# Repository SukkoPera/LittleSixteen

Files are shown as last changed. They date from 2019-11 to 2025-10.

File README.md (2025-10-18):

# LittleSixteen





LittleSixteen is an Open Hardware remake of the Commodore 16, 116 and Plus/4 home computers, featuring many improvements over the original design.

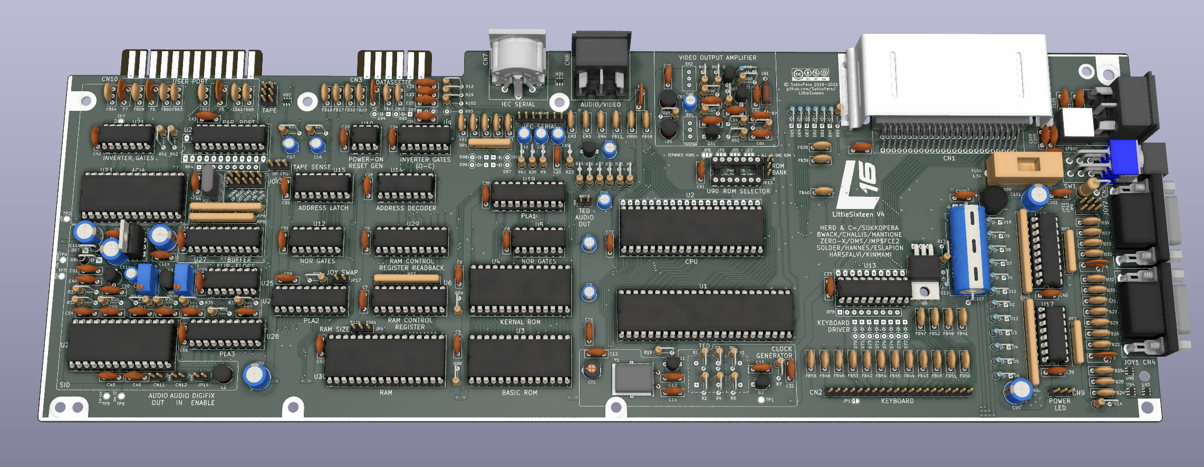
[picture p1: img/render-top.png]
Board


## Summary
While this project started as a simple redrawing of the C16 schematics, it has now evolved into what could be considered the flagship member of the 264 family of Commodore computers, since it has all the characteristics of the other models [^nospeech] and bears a full array of extra features and improvements, while keeping full compatibility with them.

The new goal of this project is to allow anyone to build a very significant home computer from the '80s from scratch, only using parts that can be found on the market [^almost]. The design is fully through-hole so no particular soldering skills are required for the assembly. The estimated cost of ALL materials (case and power supply included) for a single complete machine is around 250-300€.

## Differences and Improvements
The original Commodore 16 was the victim of several cost-cutting measures during its design phase. Its target price was $99 and Commodore still had to have some margin on that, so they really had to spare every cent they could and they went as far as not mounting the decoupling capacitors for a few chips which happened to have another one "close enough". Thus, a further goal of this project was to undo all of those measures and make the design as clean as possible, while also improving on it.

### Modifications introduced in V4
The goal of V4 was to make LittleSixteen an improved Plus/4 clone, rather than a C16 clone.

- 100% Plus/4 compatible User Port.
- 512 kB Hannes-style RAM expansion (which can be reduced to 256 kB through a single jumper for compatibility reasons).
- 2 ROM banks, each of which can carry the whole set of ROMs: KERNAL + BASIC + Function ROMs.
- Onboard SID (either 6581 or 8580 + Optional Digifix) + 3rd joystick port (SID audio is mixed with the TED/Ext audio with configurable volume but direct dedicated output is also available).
- Direct TED audio output connector.
- Joystick swapper.
- Ability to replace keyboard MOS 6529 with 74x273 (so that 6529 can be recycled for User Port, but that one as well can be replaced with a 74x654).
- Removed FB13 in order to reduce luma/chroma crosstalk and improve video quality.
- Pin header with all tape signals (think Internal Tapuino).
- Pin header with all IEC signals (think Internal SD2IEC).

### Modifications introduced in V3
In V3 we started making improvements to the board. The reasoning behind every modification is detailed on the [Development Blog](https://hackaday.io/project/182543-littlesixteen-commodore-16-mainboard), so I'll be pretty terse here.

- Switched to external power regulation, using the C64 power circuit and power supply: drastically reduces the heat inside the case, which is one of the main CPU/TED failure causes.
- Added current-limiting resistors on all ports exposing power pins: this will avoid short-circuiting the power supply, whatever you do on the external connectors.
- Added internal Joystick port buffers: this is basically like having two [OpenC16JoyAdapter](https://github.com/SukkoPera/OpenC16JoyAdapter)s built into the machine, preventing the TED pins to be directly exposed on the joystick ports, which is another common cause of TED failures. It also gives the ports a fixed ground, allowing the use of "advanced" joysticks with autofire functionalities for instance, which require power from the machine.
- Joystick ports now use DB-9 (more properly: DE-9) connectors, just like any other machine of the era: you can now use your favourite C64/Amiga joystick on your C16.
- Similarly, the Datassette port was changed to the C64-style edge connector. An adapter to keep connecting the 1531 Datassette is trivial to make.
- Moved to the C64 power switch, since this can still be found on the market and is functionally equivalent.
- The CPU can now either be an original 7501/8501 or even a 6510, thanks to [Andrew Challis's adapter](http://hackjunk.com/2017/06/23/commodore-16-plus-4-8501-to-6510-cpu-conversion/) being integrated on the board.
- In a similar fashion, the board can either directly accept an original MOS 251641 PLA or [Daniël Mantione's GAL16V8-based reimplementation](https://www.freepascal.org/~daniel/c16pla/).
- The design flaw that prevented the usage of cartridge-based RAM expansions was fixed: you can now plug in an [OpenC16RamExpansion](https://github.com/SukkoPera/OpenC16RamExpansion) without the internal RAM fighting with it.
- Actually that might not even be necessary, as the board now directly supports either 16 or 64 kB of internal RAM.
- Since the RF modulator is basically useless these days, a [replacement circuit](https://github.com/mbarszcz-pcb/c64-rf-modulator-replacement) was integrated on the board, providing either Luma+Chroma (say S-Video) or Composite Video.
- Added the possibility of combining the KERNAL and BASIC in a single all-in-one ROM: this allows replacing the original power-hungry chips with a single W27C512, which can also incorporate the Plus/4 function ROMs.
- ESD protection was improved on all ports.
- The track and ground plane layout were optimized in a few places in order to reduce noise and crosstalk.

While the comprehensive switch of connectors to the C64 counterparts might be frowned upon, it was done because [C64-style cases](https://icomp.de/shop-icomp/en/shop/product/c64c-case.html) are still in production and this way LittleSixteen V3 will fit them just perfectly, yielding the ability to build new C16s from scratch, which is another one of our goals.

### Modifications introduced in V2
V2 was meant to be a 1:1 copy of the original board with some essential improvements requiring minimum effort. The goal was to have a proved-working design we could start from in order to make improvements.

- The original board was probably laid out by hand and a lot of tracks were drawn with arbitrary slopes. I have sticked to only 45 degrees tracks, which of course means I could not follow the original tracks exactly, but I tried to stay as close to them as possible and to keep all the "visual hints" that allow identifying a track quickly. I must admit I'm quite satisfied of the end result, to be honest.
- I used my usual track widths and via sizes (plus some new values for the larger tracks), I didn't bother figuring out what sizes the original board used.
- All tracks were laid out "by eye", which means with *reasonable* - not *maniacal* - accuracy to the original design. Most care was taken in the positioning of components that ought to be in a certain position (i.e.: screw holes and I/O connectors), to ensure drop-in replaceability. Other components and tracks are "more or less" there, but as the board was wholly laid out from scratch by hand, don't expect sub-millimeter accuracy.
- The footprints for all DIP chips use "long pads". This makes them easier to solder and more solid to the board should you need to rework them. This forced a few tracks running very close to the original pads to be slightly offset away.
- Some footprints are slightly longer/larger/wider pitch/whatever than the originals, so that I could use ready-made KiCad libraries.
- Footprints for the connectors and modulator were taken from [StormTrooper's Plus/4 remake](https://github.com/StormTrooper/Commodore-Plus4), without checking them for correctness.
- I didn't bother to create the right footprint for the original power connector, as there's no point in wasting time for some item that is nowhere to be found these days. I used a much more common one instead. Same goes for the inductor.
- I didn't pay much attention to the silkscreen, many labels can probably be placed better, but I added a description for every IC, like it or not.
- Proper footprints were added for all the protection diodes that Commodore forcibly retrofitted on real boards (See D96-99).
- With the C16, Commodore went as far as saving a few cents by not mounting the decoupling capacitors for a few chips. They left the pads on the board but removed all silkscreen indications. These were restored and assigned random numbers.
- The ground fill is autogenerated by KiCad, so it won't match the original exactly (not even close).
- Probably there's something more I've forgotten.

If you don't like any of the above, feel free to fix it yourself and [submit a Pull Request](https://github.com/SukkoPera/LittleSixteen/pulls).

## Testing
V3  and V4 of the board were throughly tested by project collaborator Edoardo Auteri, as you can read on the [Development Blog](https://hackaday.io/project/182543/log/202804-how-to-make-the-changes-that-change-everything). In his words:

> The machine works flawlessly providing superior audio and video performance, low power consumption and compatibility with the 1530 Datassette Unit (C2N model), SD2IEC, Atari joysticks and pads.

## Assembly
If you want to build your own board, **please make sure read the assembly notes on [the Wiki](https://github.com/SukkoPera/LittleSixteen/wiki) carefully!**

Note that there are different pages for different revisions of the board.

## Releases
If you want to get this board produced, you are recommended to get [the latest release](https://github.com/SukkoPera/LittleSixteen/releases) rather than the current git version, as the latter might be under development and is not guaranteed to be working.

Every release is accompanied by its Bill Of Materials (BOM) file and any relevant notes about it, which you are recommended to read carefully.

**I am not providing ready-to-use gerber files**. If all you want is **to get boards made, I would really appreciate if you did so [in a way that supports the project](#support-the-project)**.

## License
The LittleSixteen documentation, including the design itself, is copyright &copy; SukkoPera 2019-2025 and is licensed under the [Creative Commons Attribution-NonCommercial-ShareAlike 4.0 International License](https://creativecommons.org/licenses/by-nc-sa/4.0/).

This documentation is distributed *as is* and WITHOUT ANY EXPRESS OR IMPLIED WARRANTIES whatsoever with respect to its functionality, operability or use, including, without limitation, any implied warranties OF MERCHANTABILITY, SATISFACTORY QUALITY, FITNESS FOR A PARTICULAR PURPOSE or infringement. We expressly disclaim any liability whatsoever for any direct, indirect, consequential, incidental or special damages, including, without limitation, lost revenues, lost profits, losses resulting from business interruption or loss of data, regardless of the form of action or legal theory under which the liability may be asserted, even if advised of the possibility or likelihood of such damages.

## Support the Project
If you want to get some boards manufactured, you can get them from PCBWay through this link:

PCB from PCBWay (https://www.pcbway.com/project/shareproject/LittleSixteen_V4_Build_your_own_Commodore_16_Plus4_fc5ed0cc.html)

You get my gratitude and cheap, professionally-made and good quality PCBs, I get some credit that will help with this and [other projects](https://www.pcbway.com/project/member/shareproject/?bmbid=41100). You won't even have to worry about the various PCB options, it's all pre-configured for you!

Also, if you still have to register, [you can use this link](https://www.pcbway.com/setinvite.aspx?inviteid=41100) to get some bonus initial credit (and yield me some more).

You can also buy me a coffee if you want:

<a href='https://ko-fi.com/L3L0U18L' target='_blank'>Buy Me a Coffee at ko-fi.com</a>

## Thanks
- My father, for buying me my C16 when I was 8, my first computer ever. This project is dedicated to his memory.
- Amiwell, for giving me a free C16 that I used to trace a lot of connections.
- [StormTrooper](https://github.com/StormTrooper/Commodore-Plus4) for his similar project about the Plus/4, which is where many of the footprints and 3D models used in this project come from.
- J. F. Gomez, for the [3D model of the Barrel jack](https://grabcad.com/library/dc-power-jack-5-5mm-x-2-1mm-2-54mm-pitch-1).
- [Edoardo Auteri](https://github.com/kinmami), for his invaluable advice on analog stuff and for fully assembling the first prototype and testing it thoroughly.
- Gordon Fecyk AKA Great White Retro, for beta-testing, making videos of his builds and spreading the word.
- Last but not least, thanks to [PCBWay](https://www.pcbway.com) for sponsoring the project and providing us with free prototypes of V3.

[^nospeech]: Ok, ok... No V364 speech support, I'll admit!
[^almost]: Almost, the CPU, TED and Expansion port connector must be recovered somehow.

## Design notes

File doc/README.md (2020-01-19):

8501 die shots:
http://visual6502.org/images/pages/MOS_8501_die_shots.html

7501/8501 pin info:
https://ist.uwaterloo.ca/~schepers/MJK/7501.html

Tech docs:
https://www.pagetable.com/?p=541

6529_replacement_for_C16.gif by Dr Jefyll:
http://forum.6502.org/viewtopic.php?t=3067#p34914

Useful info:
https://www.associazione64.it/home/il-commodore-16/#ics

Modulator Rauswerfen:
https://www.forum64.de/index.php?thread/44092-hf-modulator-rauswerfen-c64c/

http://cbm-hackers.2304266.n4.nabble.com/CPU-Replacement-for-die-264-series-td4501523.html
About GATE IN:
 From the TED system manual:

R/_W is latched by the Gate In line to synchronize between a DRAM memory
cycle and the processor clock cycle. If AEC is low when Gate In makes a
low to high transition, the R/_W line will go to a high impedance state
until the next transition of Gate In and AEC is high prior to the
transition.

It shouldn't be difficult to make that work, but so far I haven't been
able to come up with a small and simple circuit for it. It would be nice
if 2 TTL chips were enough.

---

Yes the gated R/w line was the major difference, it was to keep the /WE
enable line valid compared to the DRAM cycle instead of the Phi clock
cycle.  I don't remember if any other changes were installed in the
processor later other than I think I remember that the port became a 7
bit.  I seem to remember that if the unused bit isn't always returned as
the same bit then the code could hang, so tie the unused port to 1 or
something if emulating with 8 bit.

I think I did the Gated Read/Write with a 74LS73 only I drove the GR/w
line high, not HiZ.

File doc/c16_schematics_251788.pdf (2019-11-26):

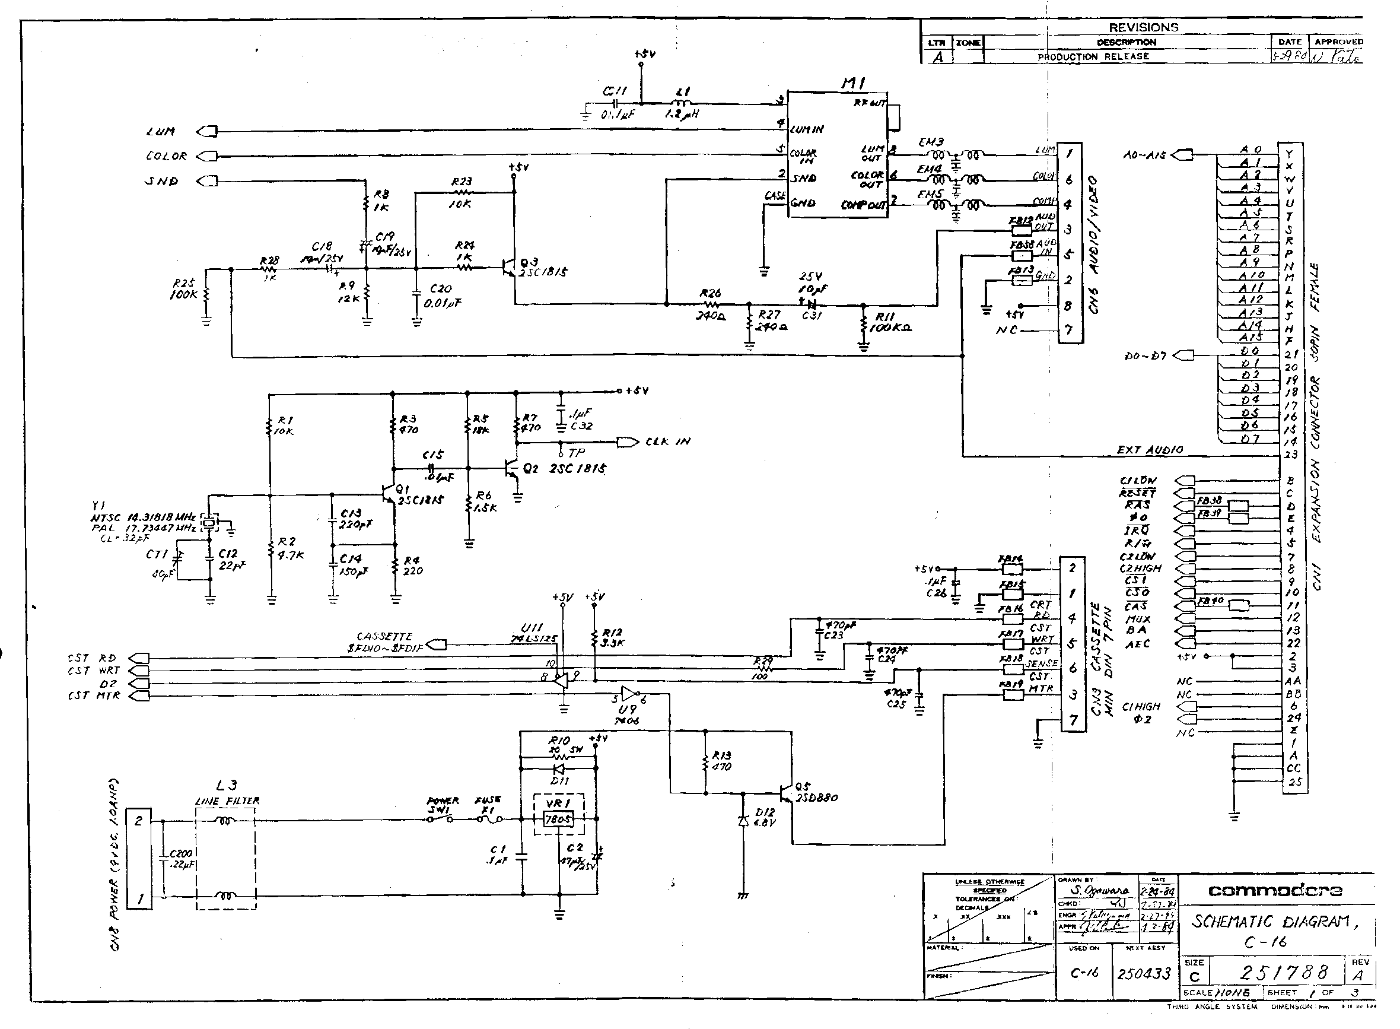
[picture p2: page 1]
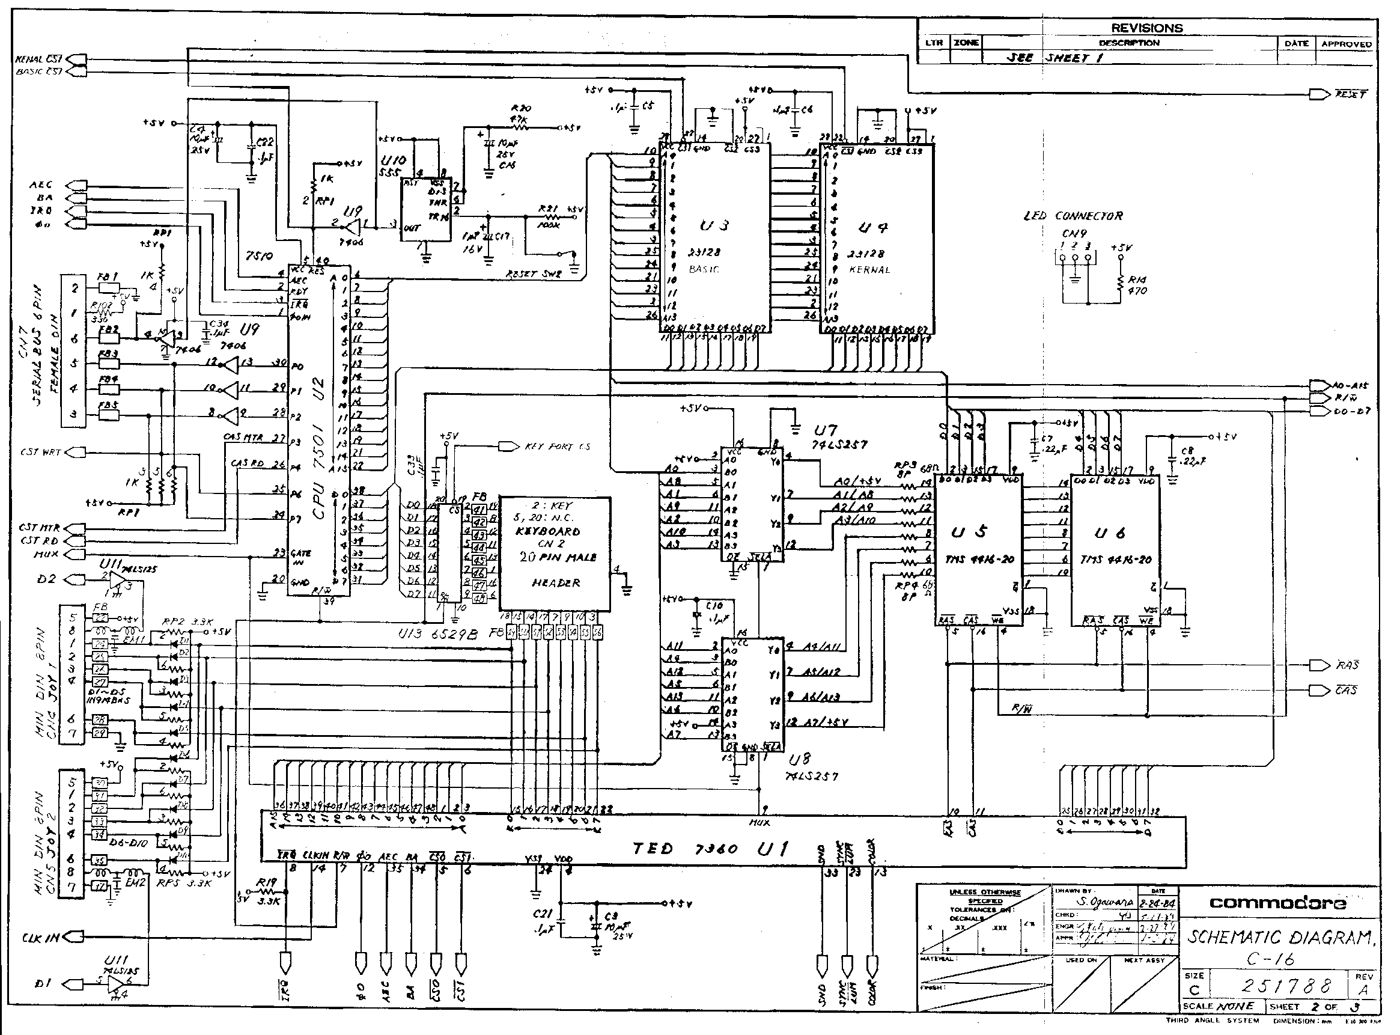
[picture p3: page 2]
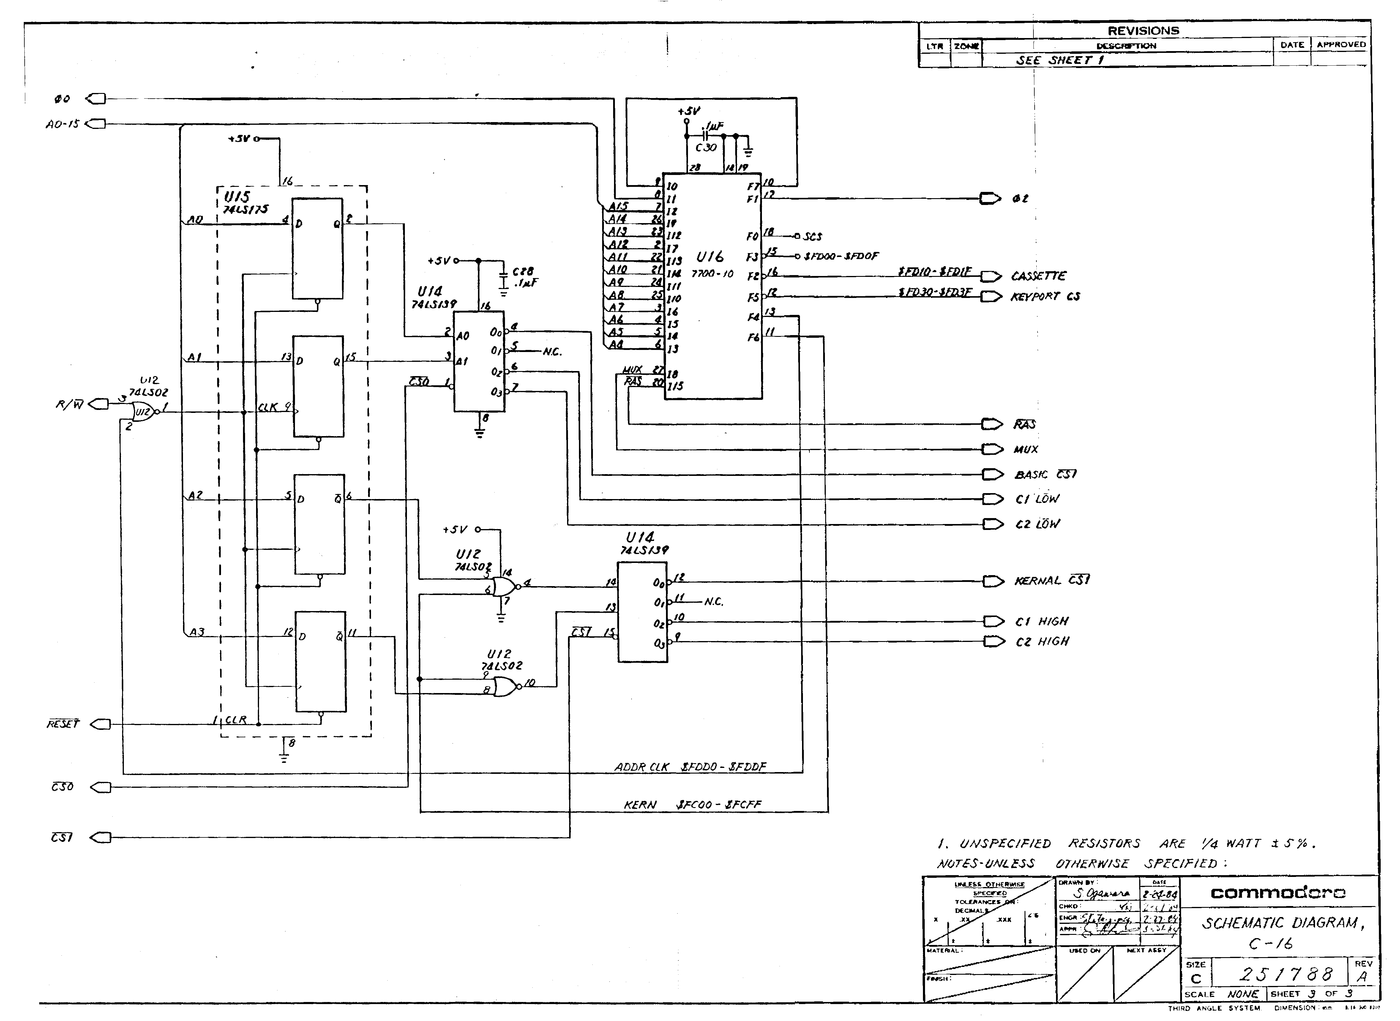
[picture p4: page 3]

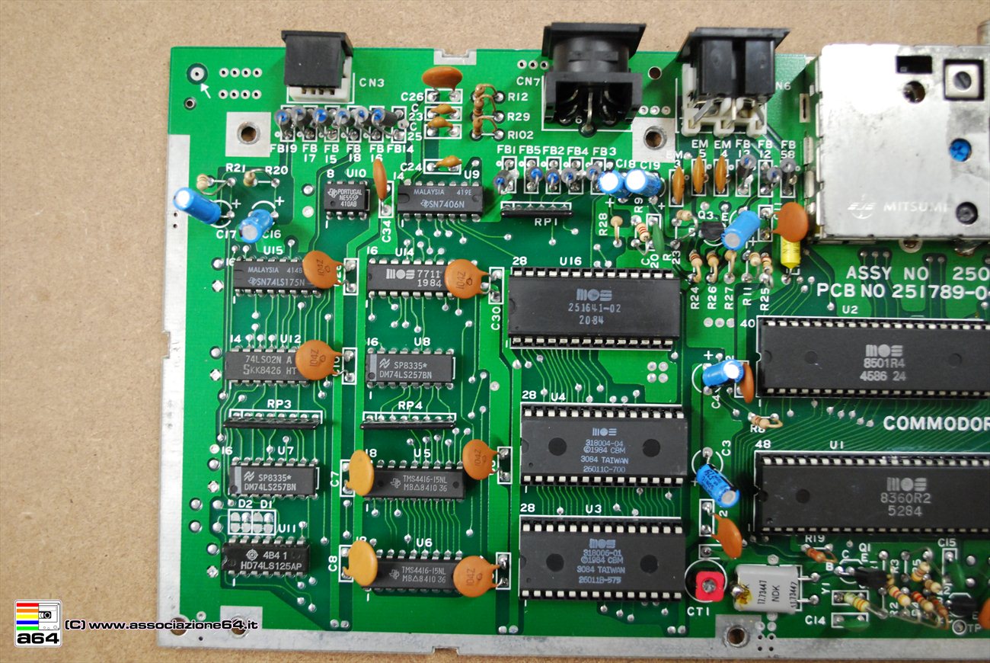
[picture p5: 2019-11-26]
doc/Commodore16_002.jpg

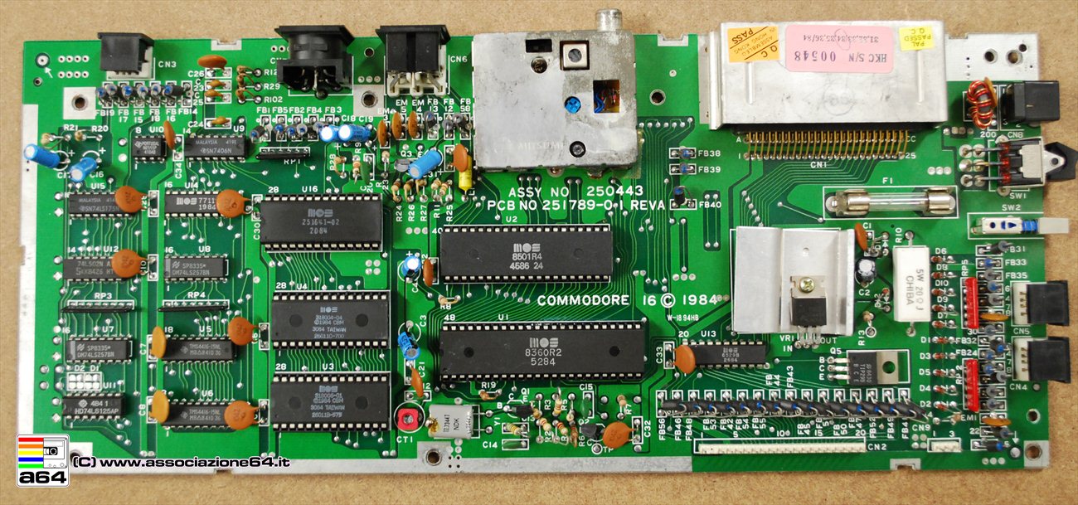
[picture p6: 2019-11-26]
doc/Commodore16_001.jpg

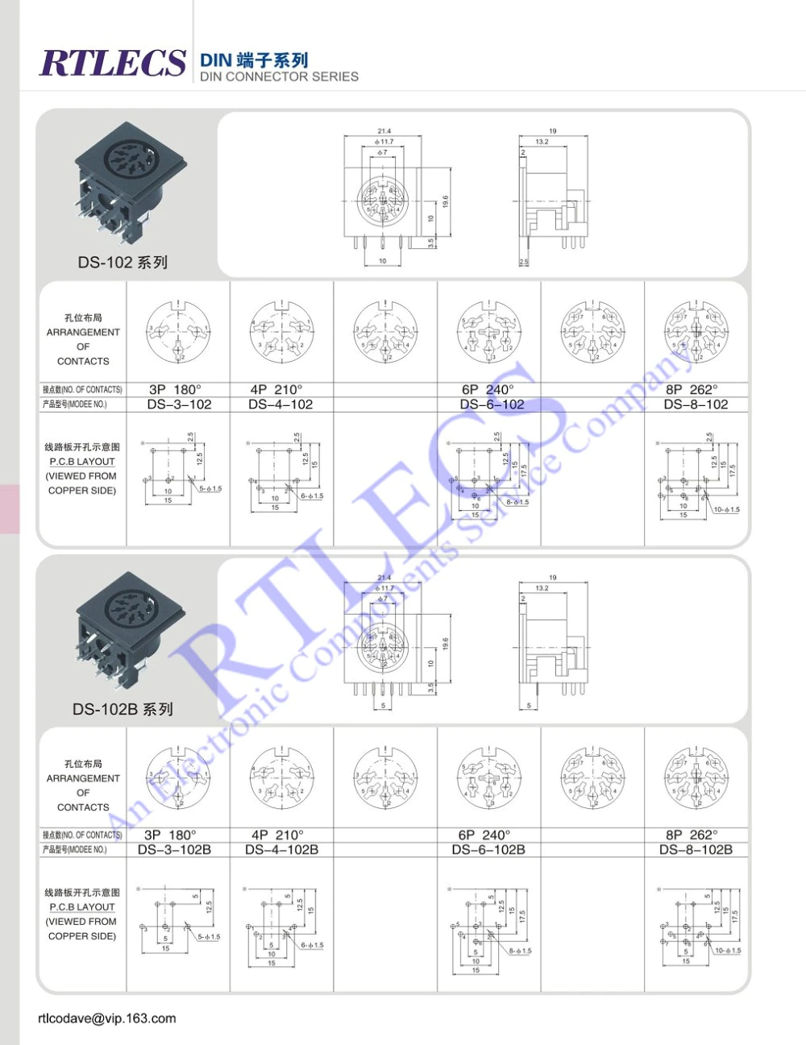
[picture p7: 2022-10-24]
doc/din_connectors.webp

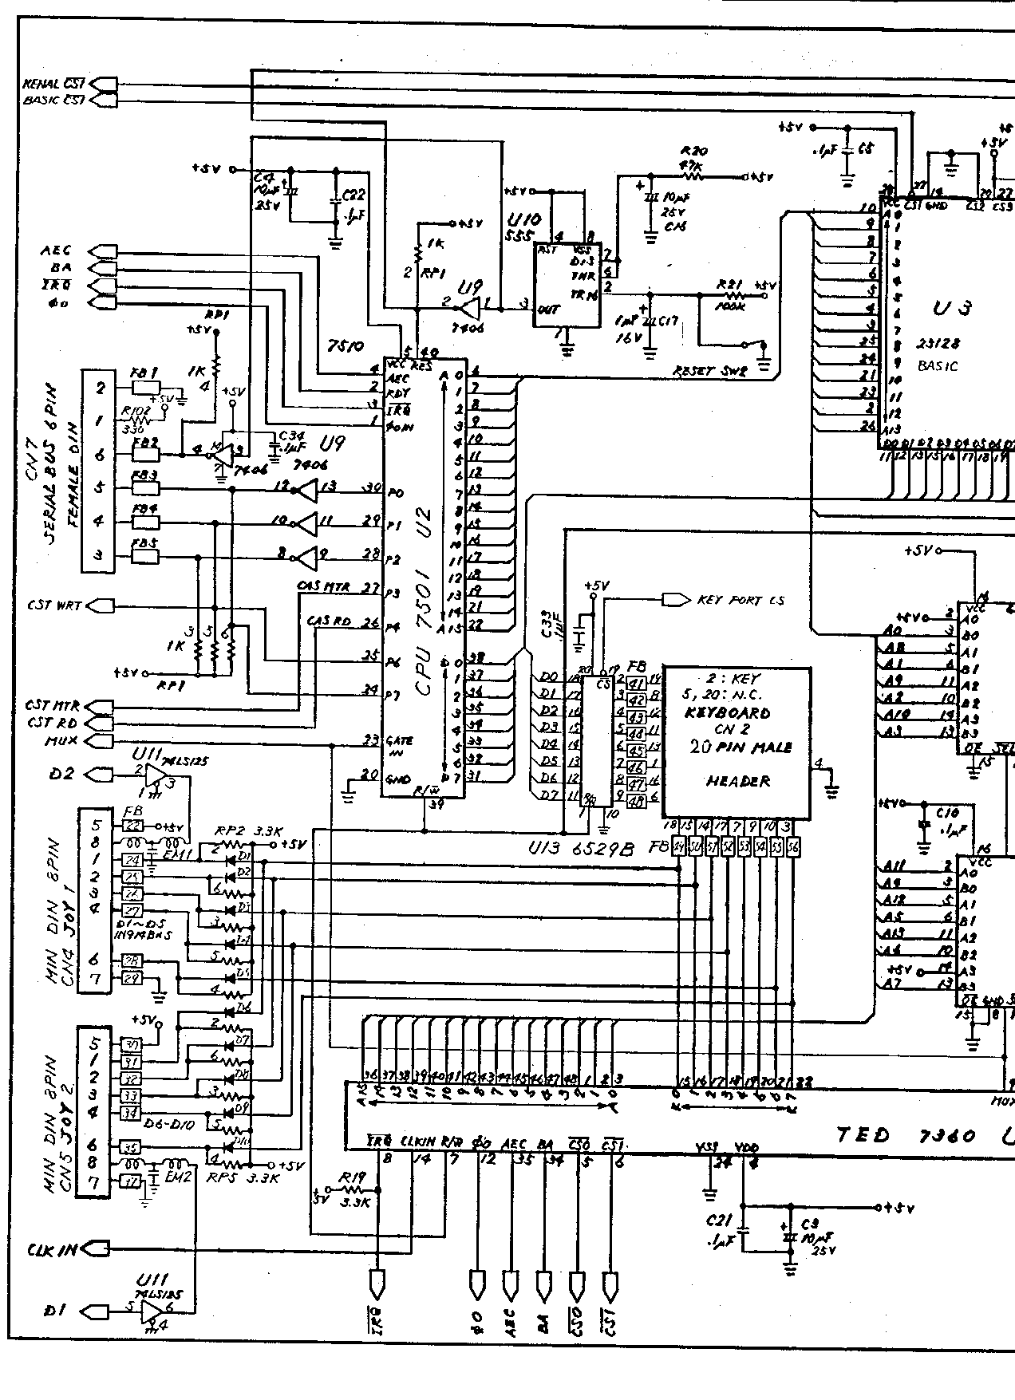
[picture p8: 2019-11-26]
doc/c16-251788-2of3-left.gif

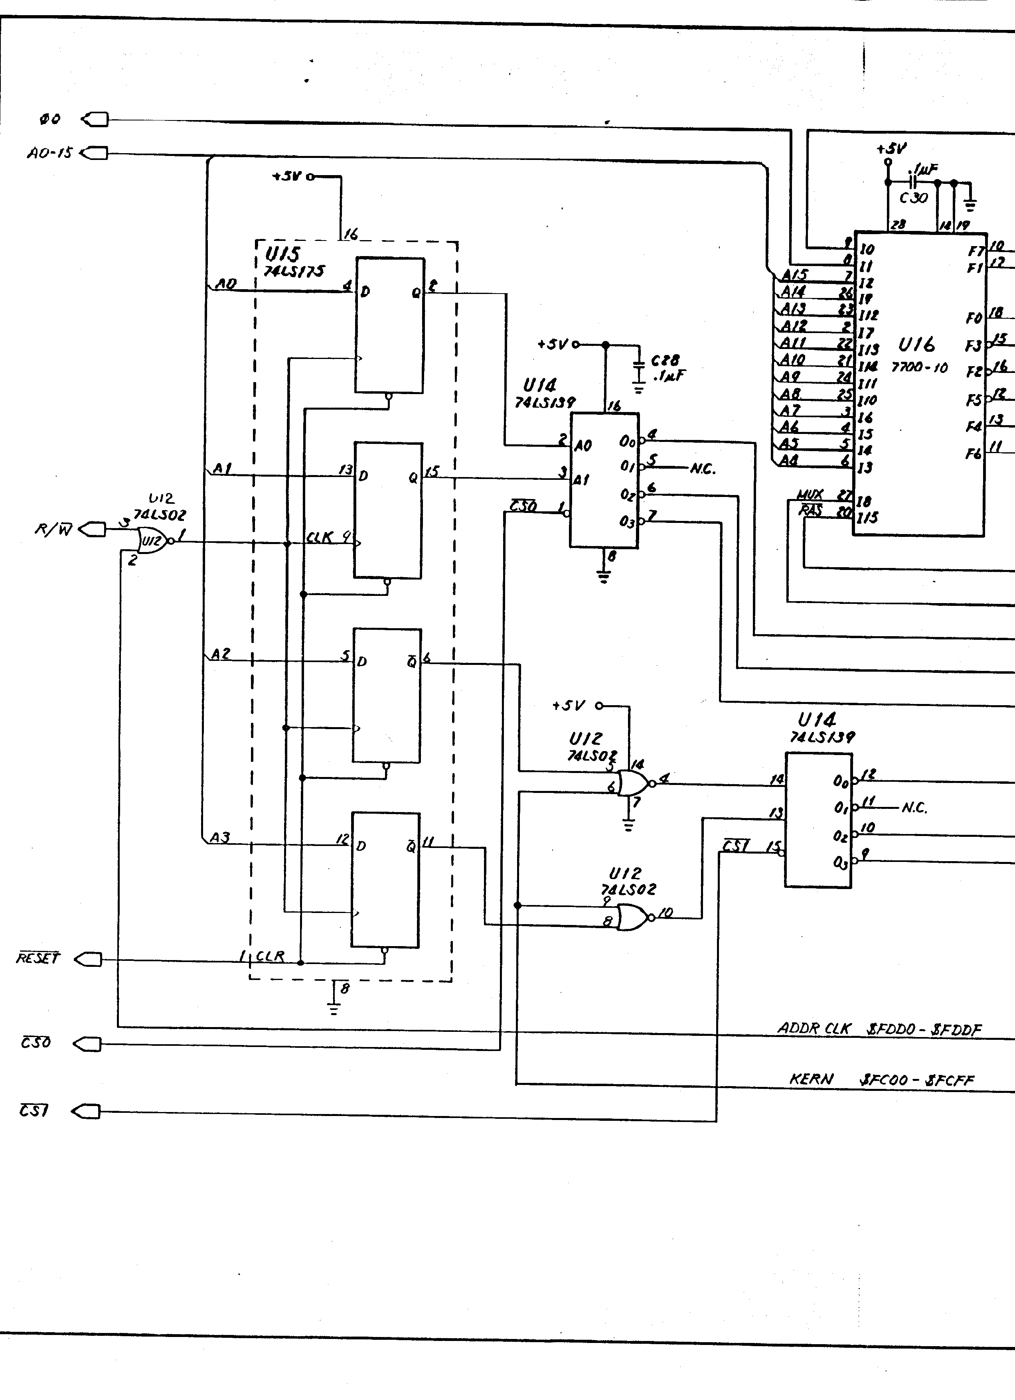
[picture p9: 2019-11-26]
doc/c16-251788-3of3-left.gif

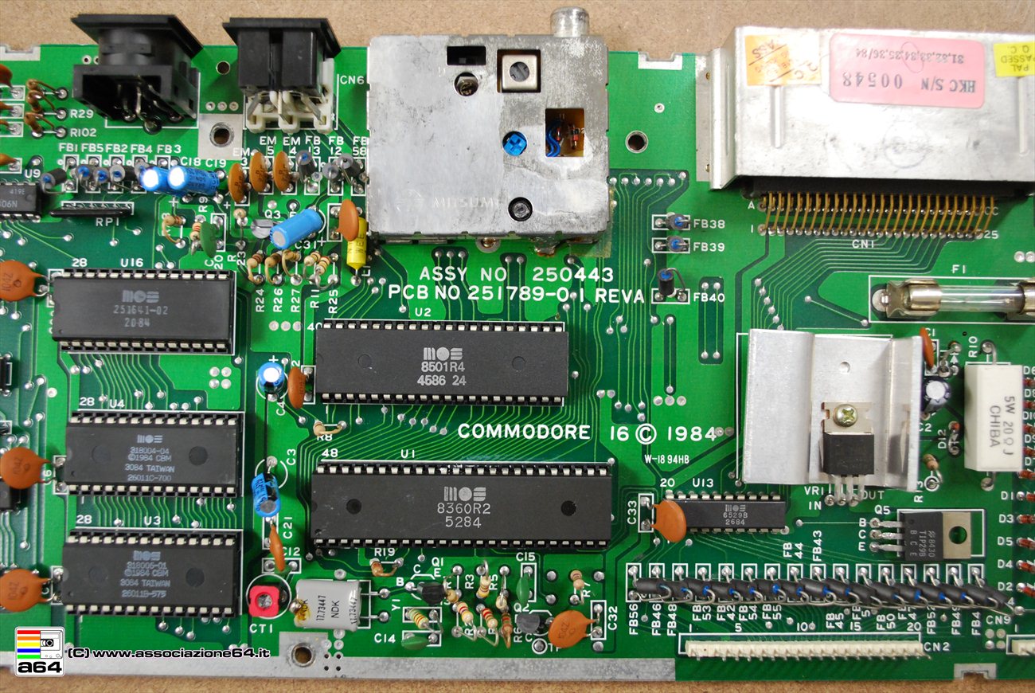
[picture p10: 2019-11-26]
doc/Commodore16_003.jpg

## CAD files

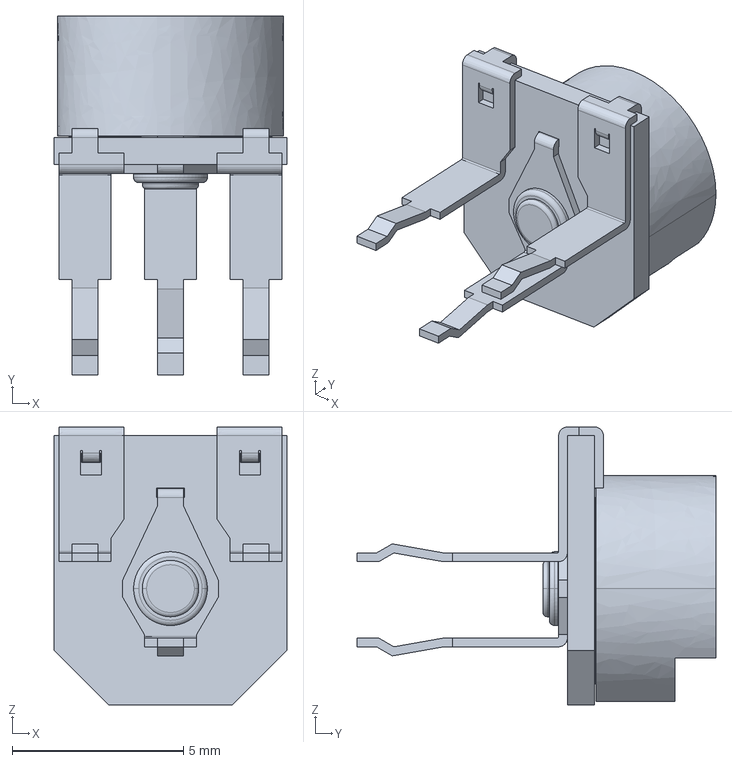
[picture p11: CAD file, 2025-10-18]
3dmodels/3306p-1-101.stp
6.81 x 10.5 x 8.13 mm

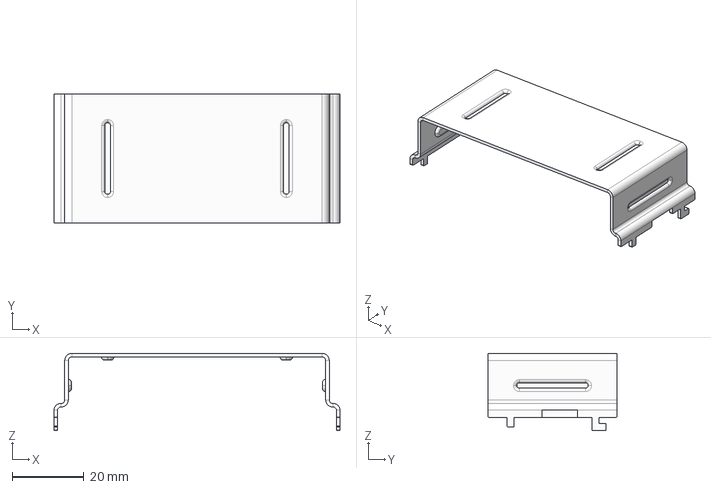
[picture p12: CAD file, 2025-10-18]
3dmodels/Expansion_Port_Cover.step
80.0 x 36.0 x 21.6 mm

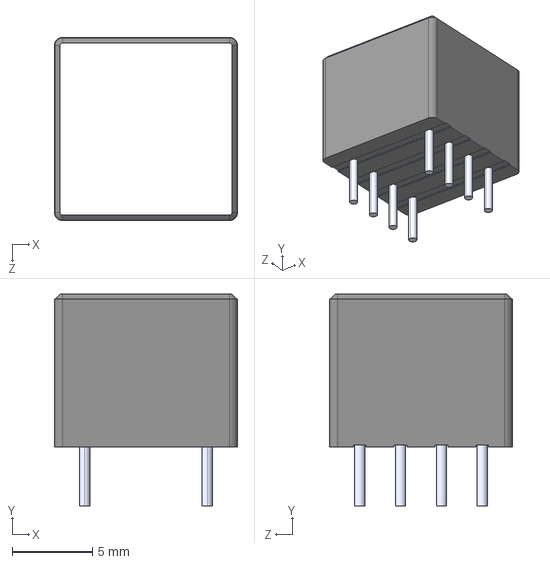
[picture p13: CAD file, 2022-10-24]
3dmodels/CM4545Z131B-10.step
11.4 x 13.2 x 11.4 mm

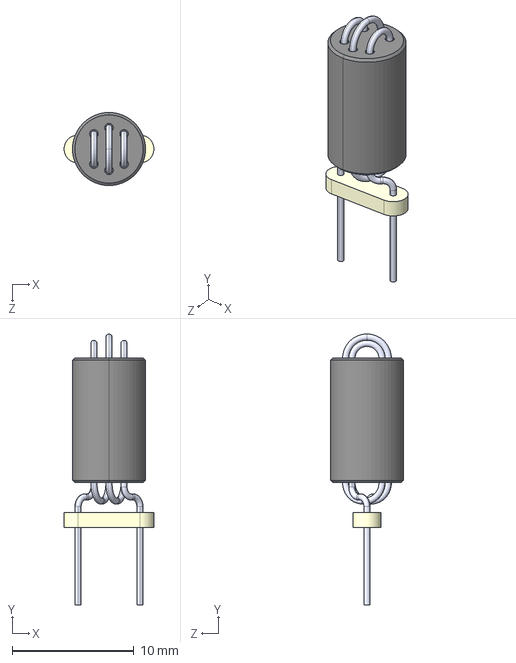
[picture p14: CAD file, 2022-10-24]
3dmodels/28C0236-0JW-10.step
7.37 x 22.2 x 6.00 mm

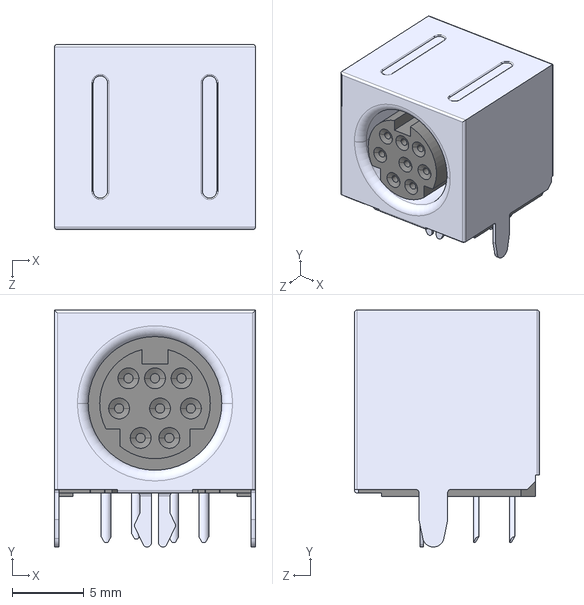
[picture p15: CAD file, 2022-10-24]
3dmodels/KMDGX-8S-BS_rC6.step
14.0 x 16.5 x 12.9 mm

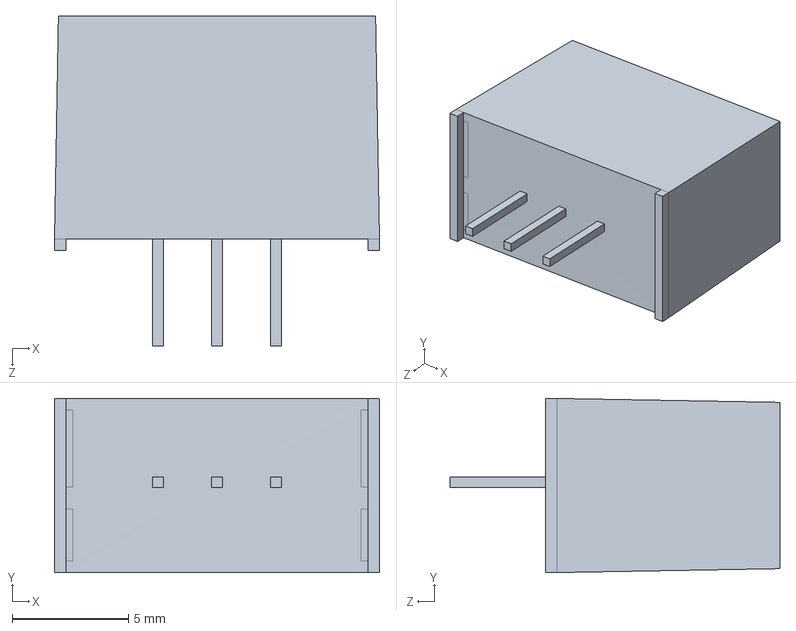
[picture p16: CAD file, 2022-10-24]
3dmodels/tsr2_3d_drawing.stp
14.0 x 7.50 x 14.2 mm

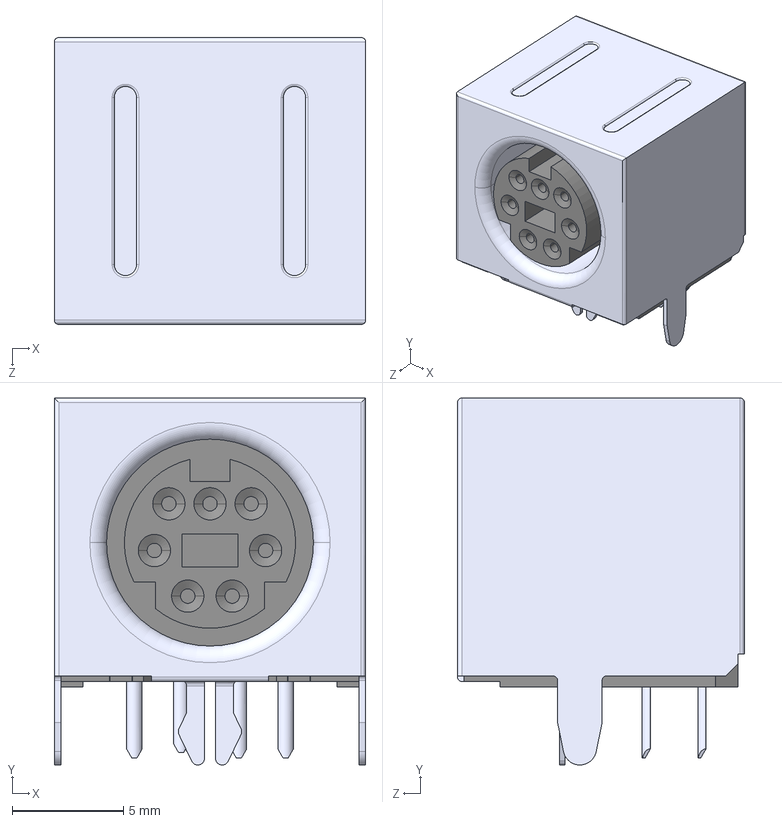
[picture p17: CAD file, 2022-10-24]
3dmodels/KMDGX-7S-BS_rC6.step
14.0 x 16.5 x 12.9 mm

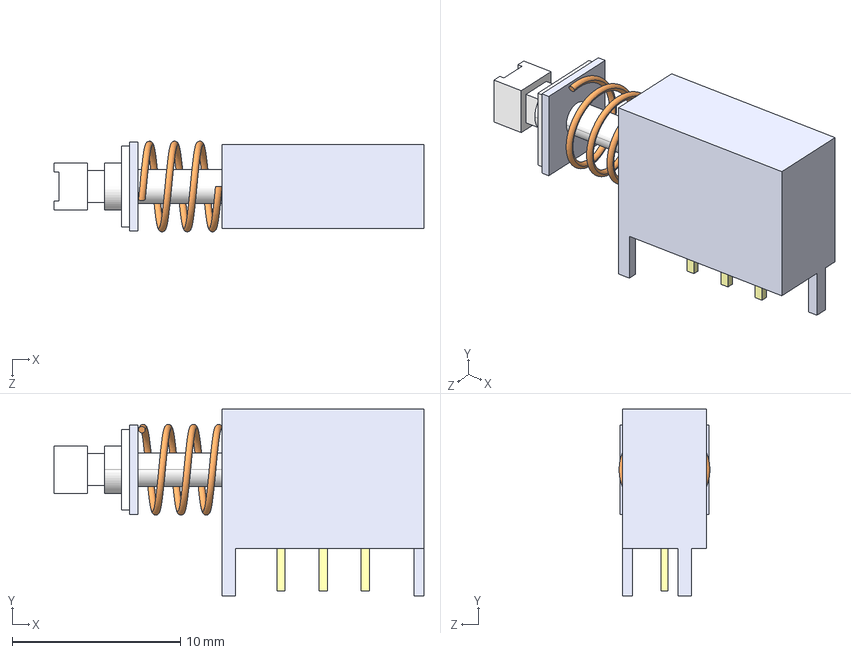
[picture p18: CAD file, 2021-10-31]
3dmodels/pushbutton-switch.step
22.0 x 11.1 x 5.40 mm

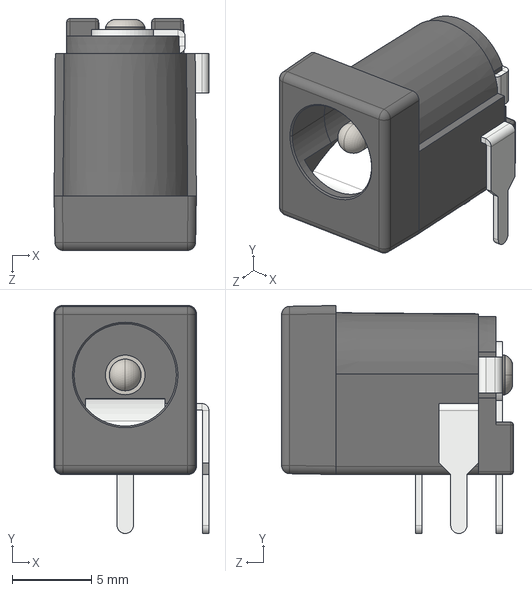
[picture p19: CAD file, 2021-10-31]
3dmodels/DC Power Jack 5.5mm x 2.1mm.STEP
9.77 x 14.4 x 14.6 mm

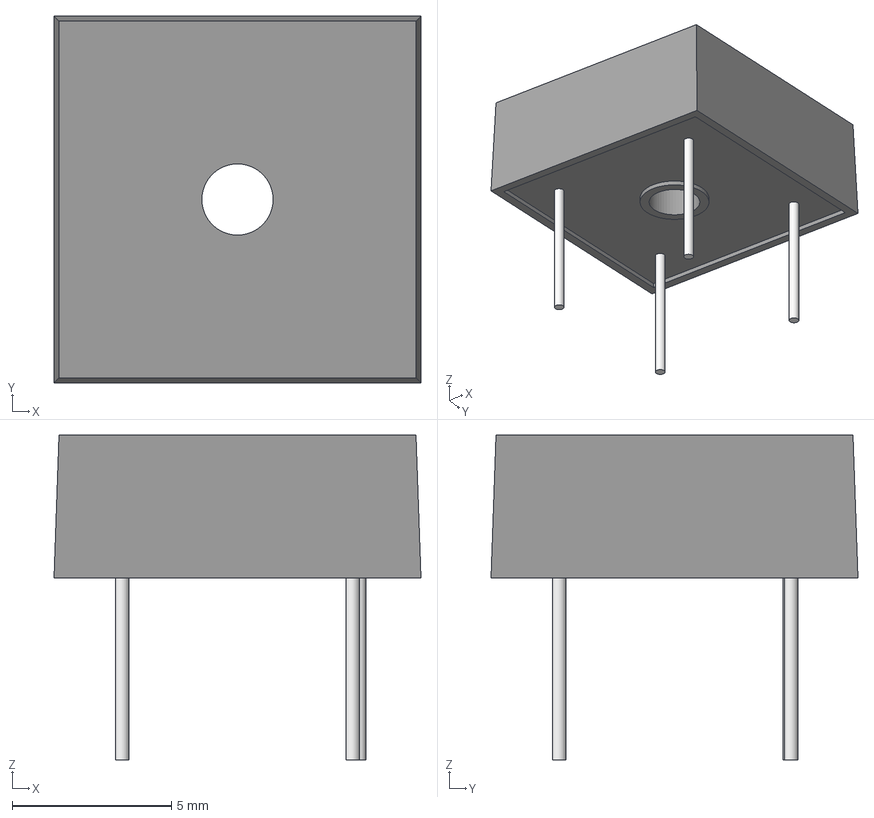
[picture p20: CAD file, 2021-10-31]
3dmodels/rectifier.step
11.5 x 11.5 x 10.2 mm

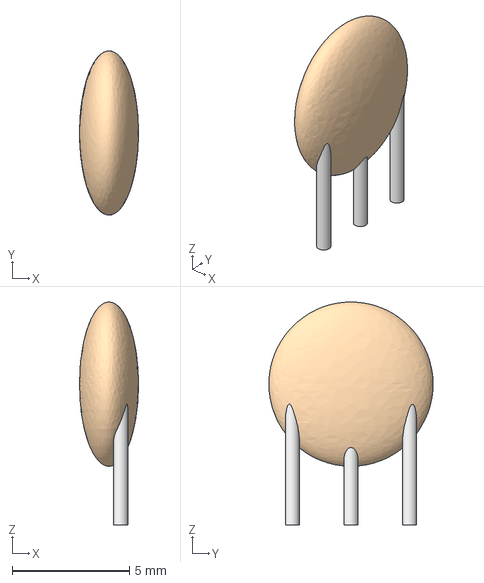
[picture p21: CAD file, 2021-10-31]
3dmodels/DSN6.step
2.52 x 6.99 x 9.50 mm

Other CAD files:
3dmodels/DSN6.FCStd

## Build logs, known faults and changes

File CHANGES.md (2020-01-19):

## CHANGES

Any modifications to the LittleSixteen design and documentation made by any Licensee MUST be noted in this file, as per *section 3.4.b* of the [license](LICENSE.pdf).

### (Date) - (Author)
(Description)

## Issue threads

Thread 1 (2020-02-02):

Looking over your schematics

bwack, 2020-02-02:
Hi SukkoPera ! I'm looking over your schematics, mainly just because of curiosity and interest :)

I found a mistake at page 11: C11 is connected on wrong side of L1.

I will notify you if I find more.

Hans/Bwack

bwack, 2020-02-02:
Page 10 (PLA): Addr_clk and KERN mixed up on U16 PLA.

bwack, 2020-02-02:
- Page 9 (power):
  - Looks like wrong power switch, and resting at ON position.
  - comment to R10 big white resistor. It provides about 200mA extra current. (9-5)V/20 ~ 200mA. It is very odd!
  - U11E and U9G on wrong page.
- Page 8: Exp conn:
  - BRESET ?
- Page 7 (cassette and disc drive):
  - The RP1 and CST WRT is shared with the disk drive signal on p6. Not clear in the schematics that p6 is shared, though I do see it now maybe because I have the original next to the new one.
  - p0..p7 on page 2 and 7: I would call them by signal name rather than cpu port io name in my opinion. I got confused.
- Page 6: I'll skip this page. It should be redrawn.
- Page 5 (ROM): OK
- Page 4 (RAM): OK
- Page 3 (TED and clock): OK
- Page 2 (CPU): OK

other:
Check pinout of all bipolars.
page 6 (keyb): I don't like this page. I like the original better. At least the P0..P7 part. I do like the comments though.
page 5 (ram): double check RP3 and RP4 connections. Original schematic is not clear here.
Page 10 (PLA): F0 and F3 looks like test/connection points in original schematics but not in new schematics. What is most correct?

Thats it. Overall, very nicely done!

SukkoPera, 2020-02-02:
Hi @bwack, it's a honor to have someone like you check my work :).

I will go through all your observations as soon as I am finished with the project I'm currently working on.

Thanks a lot, I really appreciate it!

SukkoPera, 2020-10-04:
I finally had a look on these, the fixes are in the fix_errors branch. In detail:

> page 11: C11 is connected on wrong side of L1.

Fixed.

> Page 10 (PLA): Addr_clk and KERN mixed up on U16 PLA.

Fixed.

> Page 9 (power):
>   Looks like wrong power switch, and resting at ON position.

This can be addressed in the PCB footprint (if ever).

>   U11E and U9G on wrong page.

Well, U9 and U11 are used in more than one page, so I felt the best place to put their decoupling caps was the Power page.

> Page 8: Exp conn:    BRESET ?

Since it is unnamed on the C16 schematics, I probably took this name from the +4 schematics, where it is defined as *Buffered System Reset*.

> Page 7 (cassette and disc drive):
>    The RP1 and CST WRT is shared with the disk drive signal on p6. Not clear in the schematics that p6 is shared, though I do see it now maybe because I have the original next to the new one.
>    p0..p7 on page 2 and 7: I would call them by signal name rather than cpu port io name in my opinion. I got confused.

As far as my KiCad knowledge goes, this is the best I can do. That's why I also added text labels clarifying the signal names.

> Page 6: I'll skip this page. It should be redrawn.
> I don't like this page. I like the original better. At least the P0..P7 part. I do like the comments though.

You are probably right, but I really don't feel like doing this at the moment. I'm all open for contributions though ;).

> page 5 (ram): double check RP3 and RP4 connections. Original schematic is not clear here.

This was traced by myself on a real board. I know it looks very odd but it simplifies the routing, that's why they did it like that, I guess.

> Page 10 (PLA): F0 and F3 looks like test/connection points in original schematics but not in new schematics. What is most correct?

I have no idea what *SCS* means for F0, while F3 is uses on the +4 as the ACIA CS. I have added in a note for the latter.

I think we can close this and open a new ticket for page 6, asking for help. Any comments?

SukkoPera, 2020-10-25:
I'm closing this as I fixed all I could. Feel free to open a new issue if you have any more comments :).

bwack, 2020-10-25:
Hi. Glad I could help :) I haven't had time to look at this again. I looked at page 6, and yes it is a lot of work to change it. What I didn't favor was the crossing. What commodore did there was to change the number order on the keyboard pin symbol.
And easy fix could be to remove all the wiring from the key connector and U13, use buses. I can try that if you like.

SukkoPera, 2020-10-25:
Sure, go ahead if you feel like it :).

bwack, 2020-12-22:
Hi Long time. I just remembered something about the work that I did on the schematics. Please use a larger grid, or try not to change the grid in schematics. A very simple job turned into a much harder one. Just saying.

SukkoPera, 2020-12-23:
I don't think I ever changed the grid size. Not willingly, at least.

I will (hopefully) have a look at your contribution during the holidays, sorry for the delay.

bwack, 2021-05-01:
Sorry about the misguided blame. I spoke with a guy on facebook. He said that in KiCad 4 there was a bug where the symbols had an 0.1mm offset to the grid, and it was fixed at a later point (causing more trouble hehe). At the time when I imported this project into kicad 5, it led me to believe you had used a tiny grid.

Closed 2020-10-25.

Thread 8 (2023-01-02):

using the 6502 instead

giobbino, 2023-01-02:
Hello!
Amazing project!
I was wondering about the chance to use a 6502 as CPU using this project:
https://github.com/monotech/MOS_CPU_Replacer

of course one could build the adapter, but maybe it would be fine to add it directly on the board (of course if there's enough space left on the board to do that...)

Well, just a thought...

SukkoPera, 2023-01-02:
That would be a very good idea, but:
1. It hadn't been released yet when I did this (or at least I was not yet aware of it);
2. It seems to still have a few compatibility issues;
3. It requires way more components than can fit on the current board.

I will definitely take it into consideration if the remaining issues are fixed AND if I ever switch this to SMD components, which would probably allow us to reclaim quite some space.

Thanks for your thoughts anyway 😉.

giobbino, 2023-01-02:
I understand. Also, I bought some boards from JLCPCB with the idea to have them ready on hand, just in case; however, since luckily everything still work fine here at home, I didn't test it yet - so I don't know if those adapters work fine or not.
cheers!
P.S. sukkopera = succo di frutta alla pera? I love it too ;-)

SukkoPera, 2023-01-03:
Well, the author of that adapter seems to know what he's doing :). I still haven't tried it either but I am keeping an eye on it.

PS: That's it, but I actually hate succo di frutta alla pera :).

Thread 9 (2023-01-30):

C64 keyboard

wiikroskop, 2023-01-30:
I built LittleSixteen but I had only the C64 keyboard.
The keyboards are very similar, but the C64 keyboard doesn't work with the C16.
 I found this article
[https://www.amigalove.com/viewtopic.php?t=1181](url)
and I resoldered the wires on the PCB keyboard to C16 standard colors.
It works fine, but it has some limitations.
Restore key doesnt work, Right Shift is ESCape , + is cursor down (!) , - is cursor up, pound is cursor left , clr is cursor right,
@ is - , up arrow is +, left arrow is Home , cursor left/right is pound, cursor up/down is @.

I found another article
[https://www.pagetable.com/?p=1050](url)
and based on that I remapped the keys in the ROM layout to the C64 layout with the exception
right shift and left arrow.

This solution does not work when the program reads the keys directly, but eg. FB16 ( filebrowser 16 ) works fine with my SD2IEC

use at your own risk :-)

SukkoPera, 2023-01-30:
Thanks a lot for the information :).

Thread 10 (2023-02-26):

Wrong Value for C15

SukkoPera, 2023-02-26:
Someone reported that C15 should be 10 nF rather than 10 pF. Original schematics seem to say ".01 uF", so report is probably correct.

SukkoPera, 2025-01-04:
Fixed in 17af5a4 for V4

Closed 2025-01-04.

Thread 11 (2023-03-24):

BOM for Little Sixteen V3 Board

Snocksman, 2023-03-24:
Hi !

Is there a BOM for the little Sixteen V3 Board available ? I ordered some Boards but could not find a BOM yet.

Greetings
Mathias

SukkoPera, 2023-03-24:
Nope, haven't had time to put one together yet. Maybe you can help with it? You can start with what you can find in Kicad.

Snocksman, 2023-03-24:
OK, i´ll have a look at Kicad. So I have something to do at the weekend... ;D
When I got the BOM ready, you can add it to this cool project.

SukkoPera, 2023-03-24:
Yup, let's leave this open then!

Snocksman, 2023-03-26:
Hi !

I have found most of the Components, but for some i need a few more informations/values (maybe an example part):

CT1
D12
EM3, EM4, EM5
FB2, FB3, FB4,...
FB12, FB13, FB14,...
L1
L81

Thank you !
Best,
Mathias

SukkoPera, 2023-03-28:
In our test build we used DSS1NB32A101Q91A for all EM* and FB*, totalling 51 of them. These filters are better than ferrites, but they also used to be more expensive, so Commodore only used them where essential, falling back to ferrites wherever possible.

These days I can't seem to find any reasonable ferrite that is significantly cheaper, so using filters everywhere is probably the best option. This one MIGHT do, but you're not going to save much anyway:

https://www.mouser.it/ProductDetail/Fastron/BEAD-4-900R-02

@kinmami: Any thoughts about that?

RP1, RP2 and RP5 are BUSSED.
RP3 and RP4, RP90 and RP91 are ISOLATED.

Other P/Ns from our test build:
CT1: EW Electronics GKG50015
D12: NZX6V8D,133 (Make sure to see the Errata page on the Wiki)
L1: Bourns 9250A-122-RC
L81: TE Connectivity SC30100KT

kinmami, 2023-03-28:
https://www.digikey.com/en/products/detail/laird-signal-integrity-products/28L0138-80R-10/1015875

https://www.mouser.it/ProductDetail/Laird-Performance-Materials/28L0138-80R-10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

SukkoPera, 2023-03-28:
I'll leave the word to @kinmami :).

kinmami, 2023-03-28:
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

Yes I think all of those above are compatible, thanks

msuontausta, 2023-03-30:
Here's our list: https://docs.google.com/spreadsheets/d/1dDgSGAWIuUnK9-j-XhQTBRzt-erFqXx8YhXyfMe616A/edit?usp=sharing

It's a bit rough around the edges and comments are in Finnish but all of the necessary information should be there. :)

SukkoPera, 2023-03-30:
Yeah! Thanks a lot! 👍

Snocksman, 2023-04-01:
@msuontausta Hey, thats cool. I could put my Reichelt order Information next to it, but I have only read permissions on the sheet.

Another question (maybe not really right to that issue): I got a W27C512. Is there any Information in which order i have to put the Basic,Kernal,Char-ROMs to the EEPROM ?

SukkoPera, 2023-04-01:
Yes, if you plan to use the all-in-one ROM, have a look at [this](https://github.com/SukkoPera/LittleSixteen/wiki/V3-Assembly-Notes#roms).

Actually make sure to read the whole document, and take care of the erratas.

SukkoPera, 2023-12-05:
You need to salvage it from an old board unfortunately :(. In V5 we'll turn it to the same connector as the C64, at least that one is still around.

kinmami, 2023-12-31:
Hello.
I have personally tested the listed parts without any problems, so I'm not certain about the root cause.
However, there is a different part number available with a capacitance of 270pF instead of 10000pF. You can try using this alternative part and let us know if it resolves the issue. Here is the link to the product: Murata Electronics DSS1NB32A271Q91A [](https://www.mouser.co.uk/ProductDetail/Murata-Electronics/DSS1NB32A271Q91A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)

kinmami, 2023-12-31:
I have tested PAL machines with different custom chips.
Please try with this ferrite https://www.digikey.com/en/products/detail/kemet/B-01-RS/10442402
It is designed for signal / audio line filtering.

kinmami, 2024-01-17:
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

A word of appreciation for your troubleshooting and reporting. We are going to update the BOM list accordingly.

SukkoPera, 2025-01-02:
Information integrated in the [V3 Assembly Notes](https://github.com/SukkoPera/LittleSixteen/wiki/V3-Assembly-Notes).

(At last!)

Jartza, 2025-01-27:
Hi!

I finally got time to assemble my LittleSixteen and indeed there was an issue with BOM me and @msuontausta  provided. Accidentally the EMI-filter was 10000pF instead of 100pF... these will definitely NOT work, if you have gotten the 10000pF (10nF) filters, do not assemble them but use ferrites instead!

I have updated the BOM sheet and removed link to wrong EMI filter, instead linking to 270pF version (as 100pF doesn't seem to be available in Digikey), and added link to ferrite beads.

Sorry about the confusion.

Closed 2025-01-02.

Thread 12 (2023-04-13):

Board is ready, but all I get is a black screen...

Snocksman, 2023-04-13:
Hi !

I got my Little Sixteen Board ready today and powered it up for the first time but all I got is a black screen. So I read the Wiki again and found out that I had to remove D93 and R93 if I want to use an original 8501 CPU... So I cut off both and tried again but still black screen... So I tested the CPU (maybe I killed it, because of the installed D93 and R93...), but it still works fine in my Plus4.

Is there something that I should do with the jumper pads JP1 & JP2 if I install 64KB of Memory ??? I found nothing about them in the wiki...

Snocksman, 2023-04-13:
OK, I got the Board running. But I have a Problem with the Colors and Picture Stability on my Upscaler.

Here is the picture how it looks like on my original C16:
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

and here how it looks like on my Little Sixteen:
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

About picture stability: The picture stays stable on the upscaler for about a minute, after that it begins wobling in one direction... looks like the characters in the picture start "walking" to the left or to the right...

Without the upscaler (connected to an old CRT), the problem with picture stability is gone, but the color problem is still there.

Any Idea about that ?

SukkoPera, 2023-04-14:
If there's anyone that can help you, that's @kinmami :).

Snocksman, 2023-04-14:
For further Information (Oszilloscope Pictures and so in) you can see my thread  on forum64: [Link](https://www.forum64.de/index.php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)

kinmami, 2023-04-14:
I assume the video cable is 75 ohms and the termination at the CRT monitor (or video upscaler+LCD) is also 75 ohms.
Pls verify on your side if the cable has a series resistor anywhere from 300 to 2K ohm on CHROMA (some cables originally made for the C64 have a series resistor).
Said that, from your scope screen captures I can see the LUMA signal is too intense and it is saturating.
Would you please adjust the trimmer or changing the resistor at the video circuit section to achieve something close to 1Vpp (LUMA) and 1Vpp (CHROMA)?
Hope it helps.

SukkoPera, 2023-04-15:
If calibration of the pots is an issue, note that the wiki has instructions on how to to use fixed resistors in their place, still providing the best output quality, thanks to relentless testing by @kinmami :).

Snocksman, 2023-04-15:
In the cable I use there is a 325 Ohm Resistor in the Chroma connection.
I was able to get a good picture using the trimmers, but the picture is getting "unstable" after a minute, when i´m using the Upscaler. When I turn the trimmer RV2 counterclockwise as far as possible (I get a very dark picture) the picture gets suddenly stable again.

SukkoPera, 2025-01-04:
Video circuit updated in V4

Closed 2025-01-04.

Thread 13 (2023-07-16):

Working with single 27C246

anarkiwi, 2023-07-16:
Hello,

Thank you so much for this wonderful project. I have just built a V3 board and got everything working - great!

I was able to make my V3 board work with just a single 27C256 (because I had trouble sourcing 27C512s) - perhaps a minor modification could be made to make this easier?

After some experimentation I found that I could simply burn kernal + basic to a 27C256, configure the V3 board for "single ROM", and install a single 27C256 instead with the Vpp pin lifted/grounded. It looks then like the C16 kernal comes up, does not find the function ROMs and just drops into regular C16 mode. I have no plans ever to use the function ROMs so this is fine for me.

Maybe an additional jumper could be added to allow the ROMs A15/Vpp to be grounded?

Thanks again for your fantastic work,

SukkoPera, 2023-07-16:
Good suggestion, even if AliExpress is literally full of W27C512 ;). I will have a look and probably do something in this regard anyway. I just don't understand why you suggest grounding the VPP pin, I think it should be tied to VCC for read-only operation. I'll check and let you know ASAP.

Thanks for taking your time to suggest an idea!

SukkoPera, 2023-07-16:
I've checked and I am now sure that VPP must be tied to VCC for normal read-only operation.

This is luckily very easy to do: just put pin 1 back into the socket and solder JP6 in the _Separate ROMs_ position (i.e.: left and center pads). Leave JP5 and JP7 in the _All-In-One_ position. This should work, let me know!

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

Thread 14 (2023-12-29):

New V3 board getting a black screen on power on

MC6809E089, 2023-12-29:
Hi,

Sorry to raise this as an issue but I've just finished building a couple of V3 pcbs (one for me, one for my brother who can't solder so well), but neither board is working at the moment. I was wondering if there are any additonal instructions, or changes that need to be made to get a V3 board working, other than those written on the wiki?

On power up, both boards exhibit the same behaviour: They output a black screen with sync to my retrotink mini, there is no other picture or sound. The boards supply voltages seem fine, 5.1V on the 5V rail, and 6.5V-ish for the tape motor, so I think they're okay. I believe I can see a clock signal, and some sort of activity on the data and address busses (I only have a bitscope, not a proper oscilliscope), and some of the chips on the board get warm after a while, but only warm, not too hot to touch or anything. I've tried the kernal version of 264 diagnostics ROM, and left it running to see if there was any audio, but nothing on screen or via the audio. I wondered if I might have gotten something wrong relating to the ROM/RAM jumpers.

The boards are configured for use with an original 8501 (lower socket), separate ROMs (all jumpers soldered to the left)  and 64k of RAM (both jumpers on the left). Do I need to do anything with JP1 or JP2?

All new components were sourced from Mouser in the US, and from the BOM linked in the BOM issue here. All original components were sourced from a pair working C16s, so that I had something to compare against. Because I built two pcbs, I've been able to swap all of the ICs between the two new boards and the original ones, and all ICs work fine in the original boards, so I believe the issue is somewhere on the new boards, either my bad soldering, or an incorrect component somewhere, rather than a failed one.

I understand that the problem is almost certainly something I've done, and could be pretty much anything but I thought I'd ask in case. Thanks in advance for any help or suggestions you can provide. :)

SukkoPera, 2023-12-29:
First things that come to mind:
1. Make sure that all resistor networks are properly _bussed_ or _isolated_ as they should be.
2. Unsolder FB38/39/40. It's still unclear why but some people experience problems when using RC filters at these positions. If that works, you can replace them with ferrite beads.

SukkoPera, 2023-12-30:
Glad you fixed it.

I don't think a 547 makes any difference wrt a 550. You have to work on the pots or even better remove the pots and just use the standard values as detailed here: https://github.com/SukkoPera/LittleSixteen/wiki/V3-Assembly-Notes#rf-modulator.

Closed 2023-12-30.

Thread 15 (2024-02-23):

V4

kinmami, 2024-02-23:
U91~95 lengthen the pad footprint and add a DOT on pin 1

kinmami, 2024-02-23:
CT1 enlarge the pad holes

kinmami, 2024-02-24:
CN6 pinout is wrong

kinmami, 2024-02-25:
to replace power resistors R91, R92, R94, R95 and R39, R40 with polyfuses (BOM list updated with the commercial p/n)

kinmami, 2024-02-25:
R32 for MOS 6581: to align the schematic and the interactive BOM list

gordonfpanam, 2024-09-10:
> R32 for MOS 6581: to align the schematic and the interactive BOM list

MOS 6581 as in a SID chip? Is this an attempt to integrate the SID for Psytronix TED titles that support SID expansion carts?

SukkoPera, 2024-09-10:
Yes, V4 has a built-in SIDcard. See https://plus4world.powweb.com/forum/47104.

gordonfpanam, 2025-01-05:
I'll be looking for the PCBWay link to order v4 boards as soon as you have it up.

SukkoPera, 2025-01-05:
@gordonfpanam: That's coming in a few days, but if you want I can send you the gerbers and you can order the board on JLC, which should be cheaper.

Closed 2025-01-04.

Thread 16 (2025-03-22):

74LS654 for v4 parallel user port?

gordonfpanam, 2025-03-22:
Going through the BOM for v4 RC16 I double checked looking for U122, a 74LS654. This part doesn't seem to exist in the XLSX BOM, nor is it in stock at DigiKey. Searches are turning up LS645 and similar parts, which have different pinouts compared to the KiCad schematic. The silk screen also specifies a LS654 part.

There is a 74**A**LS654 part that uses open collector outputs, which I suspect is the reason for RP4 being used as pullup resistors. Is this the intended part?

I won't need these parts until later in my build as I'm focusing on the Commodore 16 part first, but I wanted to confirm if I'm supposed to find a real LS part, or if the ALS part will work. I don't have the original MOS 6529s to spare.

SukkoPera, 2025-03-22:
A 74x654 is needed, definitely not a 645 nor anything else.

All 74x654 are open-collector by definition and so is MOS 6529 (but the latter also has internal pullups), that's why this particular part was chosen.

We have tested LS, ALS and ACT parts and they all work, like probably many others.

Unfortunately all of these in the DIP package are not easy to find these days. They have quickly gone out of stock on all the main distributors.

I suggest that you look on eBay or maybe buy [the 6529 replacement by Daniel Mantione](https://www.sellmyretro.com/offer/details/mos-6529-spi-full-equivalent--_-soldering-kit-43923) and just use the 654 chip or even ask him if he can provide a few chips.

gordonfpanam, 2025-03-22:
Is the ALS654 part compatible, then? These at least seem to be in stock at a few places.

Closed 2025-03-22.

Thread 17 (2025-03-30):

No NTSC Colour on v4

gordonfpanam, 2025-03-30:
I'm not getting any colour on NTSC with a 14.31818 crystal and NTSC kernal. Depending on the monitor, I could get either no colour at all in NTSC or PAL, colour in PAL but no colour in NTSC, or colour in PAL but flickering between colour and monochrome in NTSC.

I've already worked back through the video amp circuits, effectively converting both circuits into v3 form, but keeping R86 as 1k to avoid drawing too much current from the TED Sync/Luma pin. I want to work forward toward v4 again until I lose PAL colour, but I've run out of time for now.

I've gathered scope captures of the luma and chroma signals and I'll try to put together a side-by-side comparison video. I've done this for the L16 v4 and for an original Commodore 16 to compare. The original C16 has very hot chroma signals but these work on any monitor in either PAL or NTSC. By comparison, when I do get colour PAL video using the Rev 3 circuits I can dial things back to 1V peak to peak (1VPP) on luma and 0.3VPP on chroma, which is supposed to be s-video spec according to The Retro Channel:

https://www.youtube.com/watch?v=agDFLPP9yIw

Doing the 1VPP luma and 0.3VPP chroma also removed checkerboarding and jailbars on the v4 board's LCA / s-video output, at least on a PAL-capable monitor that displayed colour.

To reproduce the problem you'll need a NTSC-capable monitor, crystal and kernal, and the current v4 video amp circuits as of RC16. JP18 didn't need to be set at all, in fact leaving it unset will clean up the s-video output some. This seemed to happen regardless of whether I installed RV1 and 2 or not, though having RV1 and 2 helped me tune the output.

SukkoPera, 2025-03-30:
There is no risk in changing - or even temporarily removing - R86. It does not control how much current is drawn from the TED outputs.

I don't know if anyone has ever built an NTSC version of V3. It's definitely uncommon to have an NTSC-capable device here in Europe, so it's difficult to help with that.

In any case, we must tackle this issue rationally if we want to get anywhere. For a start, I suggest that you go 100% back to the V3 circuit, which has been proven working by several independent builders, so please switch to the following values and report back:

R81* = 3.3k
R82* = 1k
R83* = 5.6k
R84 = 150
R85 = 220
R86 = 470
R87* = 150
R88* = 150
R89 = 150
R90* = 150

C81* = 330p
C82 = 68p
C84 = NOT MOUNTED
C85 = NOT MOUNTED (but won't hurt anyway)
C86 = NOT MOUNTED
C87 = NOT MOUNTED

JP81 and JP82 CLOSED
JP18: 1-2

An asterisk indicates values that haven't changed between V3 and V4, so it should be sufficient to check that those parts have the correct value.

gordonfpanam, 2025-03-30:
Just some positive feedback for this whole process… this is my first scratch build for a modern retro PC and your support so far is excellent.

gordonfpanam, 2025-03-30:
How much trouble would it be to ship you a flat panel monitor capable of both NTSC and PAL with composite and s-video inputs? I could find something that just has a 12VDC or 5VDC power input that would let you use a locally sourced power supply.

I suspect such monitors are also readily available on eBay. It's where I got a few of mine. I sourced others locally from thrift stores and flea markets.

SukkoPera, 2025-03-31:
Thanks for the offer but no, at the moment I'd prefer to avoid that. You're going to be our reference for NTSC! :)

krzycho751, 2025-04-01:
Hi guys,
I recently built a V3 with an NTSC crystal and ROM. I can confirm it works!
I went with a simplified setup, leaving out RV1 and RV2.
The video signal isn’t great (visually — I haven’t hooked it up to a scope yet), but I suspect it’s due to a noisy environment and a less-than-ideal PSU. I’m getting wide bands of noise slowly drifting from bottom to top on the screen.
For display, I’m using a ~10 year old Samsung TV, which might also be contributing to the issue.

gordonfpanam, 2025-04-01:
Well this is embarrassing…

I put in the v3 circuits as you asked but still got only monochrome. But on a lark I tried adjusting the variable capacitor at CT1 and I got colour NTSC.

*facepalm*

It’s a bit dark compared to my prior tests, but I’ll put back the v4 circuits and try again.

I think RP1 and RP2 are still important at least on this test build, but I’ll try to measure the effective resistances and see if they match your recommended values for omitting those.

So it appears a precise crystal clock is really important for colour video. My scope doesn’t measure high frequencies very well, being a cheap Hantek USB model, but maybe I can get a precise horizontal sync value at least.

gordonfpanam, 2025-04-02:
OK I determined that the original V4 circuit can do colour NTSC. It doesn't do it _very well,_ but it can do it.

The hybrid v3/v4 circuits I had two days ago seemed to do a much better job, but at least the current v4 circuit works well enough.

One thing I noticed that when I put the composite mixer back into service, JP18 towards the cartridge port worked much better than JP18 towards the user port. Both are pretty dirty, but JP18 towards the user port looked a lot like Apple II artifact colour when I had the monoscope generator program on screen 1 for that. I had fewer video artifacts, less checkerboarding, and less jailbars with JP18 set to the right and

So for general purpose use, I'd recommend building out the v4 circuit, but with JP18 set to the right (towards cartridge port) but with RV1 and 2 installed, so a user can adjust the video signal amplitudes. When JP18 is set, Luma almost doubles in amplitude up to 2VPP and needs to be dialed back using RV2. Even without a scope, one can eyeball the picture quality and tune it using first adjusting CV1 to get colour, then RV1 for brightness, then RV2 for less checkerboarding and jailbars.

For a perfectionist that has access to an LCA or s-video monitor, and as long as they will use s-video exclusively, I would recommend a hybrid of the v3 and v4 circuits with the composite mixer and associated transistor completely omitted. With the composite mixer omitted you'd need to dial RV1 and 2 back up but you'd get a very clean picture. I'll write something up as a supplement (optional for perfectionists only) for the Wiki when I've come back to that.

SukkoPera, 2025-04-08:
I've added basic info about this to the wiki. Feel free to reopen to submit the info for perfectionists, I will move it to the wiki in turn.

SukkoPera, 2025-04-08:
If you want to add info for perfectionist, please start from this text I've just added to the wiki:

https://github.com/SukkoPera/LittleSixteen/wiki/Fine%E2%80%90Tuning-the-Video-Signal

Closed 2025-04-08.

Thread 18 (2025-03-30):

Potential Short Circuit with Metal Keyboard Frame on v4

gordonfpanam, 2025-03-30:
On a 64c case with original metallic keyboard frames, there is a significant risk of short-circuiting unused surface mount pads for U93, U94 and U95. Metallic frames are outright unusable if these are installed instead of the through-hole diodes for electrostatic discharge protection.

Under recommended conditions, U93 through 95 would be installed instead of the diodes.

In addition, U17 and U18 sit too high on the board if socketed and an original metal frame is used. RP2 also doesn't allow the metal frame to sit correctly.

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

To work around this, install U17 and U18 directly to the board and modify the metallic frame, or modify the frame further to allow more clearance for socketed U17 and U18. Use electrical tape around the mount point to prevent shorting against the pads for U93-95. Alternately, a 3D-printed plastic frame for a 64c keyboard may avoid this entirely.

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

SukkoPera, 2025-03-31:
Thanks for this report, I will move it to the Wiki ASAP.

SukkoPera, 2025-04-08:
Done.

gordonfpanam, 2025-05-05:
I don't need to re-open this specific issue, but at some point I'll try fitting a 64c short board RF shield on one of my two builds to see if there are any more potential short circuits or fitting problems. Today's US FCC isn't as paranoid about RF emissions, but I'm curious.

Closed 2025-04-08.

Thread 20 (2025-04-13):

JPs 81 and 82 shorted under solder mask

gordonfpanam, 2025-04-13:
I found it difficult to adjust luma and chroma levels on my second build, but discovered that the RV bypass jumpers for omitting RV1 and RV2 are shorted from the factory.

Inspecting the PCB layer used by these in KiCad confirms a possibly unintended short under the solder mask.

I had to cut the traces under the mask to use RV1 and RV2, which allow better control of luma / chroma / s-video output and reduces video artifacts. Maybe changing R87 and R84 to different values will get better results, but I’m pretty sure leaving these shorted wasn’t intentional.

SukkoPera, 2025-04-13:
This was actually by design, since we thought the easy way would be sufficient for most users.

But maybe it would be better to let the user close the jumper, I will think about it. In any case the instructions should be made clearer.

Oh, and I'm surprised that you didn't do this on your first build!

gordonfpanam, 2025-04-13:
I think I did the cut by accident the first time. I went to remove the solder from the JP8x pads to find the wick “wasn’t working,” then took a dremel to them.

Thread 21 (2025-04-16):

Question: 6581 or 8580 preferred for SID chip?

gordonfpanam, 2025-04-16:
I tried three 6581s across two L16 v4 builds and got different results for all three SID chips.

To compare the two I ran the Giana Sisters Demo for the plus/4 on the L16 and compared it to the real Giana Sisters game on the C64, and I also ran a demo whose name might trip some content filters here but uses digital audio playback.

The first SID sounded like trash, but sounded fine on a C64 longboard. The digital audio especially had some artifacts.
The second SID sounded almost perfect, in fact it's the same one in the YT Short you linked to in the Wiki.
The third SID was much better than the first, but still sounded off in the Giana Sisters Demo. Digital audio was much better. The initial loading screen ping for Lykia was also somewhat off on the third SID but much better on the second.

I was careful to make sure the SID area of the board was built out identical on both, using the correct voltage regulator for instance, for 6581s. I could swap in 8580s and the other regulator but I'd also have to swap in a few other discrete parts.

Considering the original SID card seemed to favour the 8580 if plus4world is to be believed, should I have gone with 8580s in these builds? Could there be that much of a difference between 6581s that they would work fine on a C64 longboard but have different behaviour on this build? Would this be more consistent using 8580s than 6581s?

As a side note, I know someone close by that has a 6581 that is iffy on a Commodore 128 flat system, but is fine on his C64 longboard as well. These are both supposed to use 6581s apparently - I checked the VSID pin on the 128 and it was +12VDC like it is for here.

SukkoPera, 2025-04-17:
I have never tested the Giana demo, but it has to be expected that SID sound on C16/L16 will not be the same as on the C64, even if you play the same song. It's a long story but the bottom line is that the chip is clocked at different rates on the two machines (~886 vs ~985 kHz) and there is NO simple way to do differently.

That said, I don't expect different chips of the same model to sound differently, so this is a bit odd. I haven't tested many different chips, maybe 3 or 4 only, but they all worked as expected (yes, all 6581's sound slightly different from each other but they all sound good).

My references for testing the SID sound are the Lykia intro and [Solder's "Ninja" demo](https://plus4world.powweb.com/software/Synergy_SIDcard_Software).

The original SID card by Solder used the 8580 only because Solder could not come up with a working voltage step-up circuit to produce 12V (which the 6581 requires, while the 8580 takes 9V). I have an email from him where he says that, he didn't have access to the data sheet of the TL497 chip so he had to "design by attempts" and it's already a miracle he managed to get the 8580 working (he has my utmost respect for that - and well, not only for that ;)). But that is the only reason, there are no others, since the SID circuit only has minor differences on breadbins and C64Cs, and those are the same differences we account for.

The bottom line is: both SID models should be working fine in L16.

That said, what values did you use for R37 and C57?

gordonfpanam, 2025-04-17:
R37 was 100 Ohm and C57 was 470 picoFarad. I checked these against the configuration doc and these didn't have any difference. These were in the interactive bill of materials.

SukkoPera, 2025-04-17:
Can you please try R37 = 220 ohm?

gordonfpanam, 2025-05-06:
I haven’t tried the alternate passives yet, but I noticed I omitted R32 on one of the builds. I think I ran out of those and just decided I didn’t need it for the initial test.

That build sounds better, oddly, than the one with R32 populated.

I’ll try populating R32 on the better sounding build when time permits.

SukkoPera, 2025-05-06:
R32 will just make the output slightly louder if omitted. Omission is required for the 8580 since it has a slightly lower output volume and vice-versa for the 6581. It shouldn't cause major issues in any case.

gordonfpanam, 2025-05-06:
Slightly louder is actually a good idea. The 6581 with R32 omitted still sounds somewhat quieter than the TED audio, but that might be subjective.

I'll have to record some waveforms using line input to compare the two, as recording from an iPhone camera won't do since the phone will attempt to compensate.

gordonfpanam, 2025-05-18:
I ended up replacing most of the 6581-specific caps and C52 with an aluminum one, and this seemed to improve SID audio a little bit, but replacing R37 with a 220R part improved things a lot more.

That's the SID clock, I think that makes a lot of sense that messing with that changes the audio quality.

Speaking of the SID clock, the schematic references JPs 15 and 16. I haven't set either of those, but this seems to only apply to the reset circuit and I haven't installed a reset switch on my builds yet. As such /S and /R are floating on U25A on both of my builds. Your notes say that tying /R to /RESET sounds better, did you mean audio sounding better, or being a more sound design?

SukkoPera, 2025-05-19:
Yeah, R37 is part of an RC network delaying the halved MUX signal which is used to clock the SID so that it overlaps with /CS during double-clock periods and writes can get through. It's a huge hack but any other solution is orders of magnitude more complicated. Anyway it should already be 220 in the BOM, I think I just have to fix it in the IBOM.

JP15/16 MUST be set to one value. I think we set them both to the left on our prototype and it seems to work well. If you don't do this, what might happen is that the clock signal starts up completely out of phase with /CS and everything will sound terrible because SID writes will never make it through correctly. If you don't connect the jumpers, you basically have a 50% chance of this happening at power-up and/or at every reset, so please do it. You might also test the different settings if you feel like it (there's only 2, either both to the left or both to the right, other combos don't make sense), but what I meant is "it sounds like a better idea", it will not make the sound quality better or worse, as it should either just make it work normally or totally disrupt the sound output.

gordonfpanam, 2025-06-22:
I ended up setting JPs 15 and 16 as you suggested, to the left / away from the joystick ports. I didn't notice a difference in SID audio quality, but it is working.

Replacing R37 with 250 Ohms (I didn't have any 220s handy) stabilized the 6581 behaviour on both builds.

The 6581s run rather warm on these builds compared to the same chips on a C64 longboard. I have heat sinks on them, but I'm going to try ARMSID on these when time permits. I'm hoping that solves the heat problem, not to mention it's one more modern part.

SukkoPera, 2025-06-22:
Uhm, I don't see how the SID could develop more heat, since it's running under exactly the same conditions it would be in a C64... (Clock rate apart, but that is actually _lower_...)

Anyway glad everything is working well in the end.

On a side note: there is a flaw in the joystick switch, I have just found out (fire buttons are not swapped correctly). Please disable it and consider it as if it was not there.

SukkoPera, 2025-06-22:
Fixed by 1d055ad73ee68405f88a19128d53e24c58057e10.

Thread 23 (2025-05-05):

74x654 Extra Inputs from SNES Adapter on v4

gordonfpanam, 2025-05-05:
Trying to use the TexElec SNES adapter on the L16 v4 and 74x654 part seems to cause additional SNES button inputs.

Using the adapter on the original PETSCII Robots plus/4 edition seems to cause additional inputs with certain buttons. For instance, using the left shoulder button also triggers the A button input. Using a modified version from https://github.com/pdaehne/SNES-Userport-Adapter/tree/main/PETSCIIRobots-patched that accounts for third-party controllers has a slightly different effect where the left shoulder button triggers the X input instead of the A input.

Holding down A causes rapid-fire A inputs. Using the right shoulder button also triggers the left shoulder button. I haven't listed all of the odd interactions.

I just put my plus/4 back together so I can't yet verify if an original MOS 6529 part also causes this. I do know that the same controller and adapter seem to behave on an original plus/4, at least using the modified version that accounts for third-party controllers.

Diag264 reports the parallel I/O pins are working as expected.

SukkoPera, 2025-05-05:
This surpises me, since when I developed [NessieSoup](https://github.com/SukkoPera/NessieSoup), I tested it specifically on a L16 board with a CD74ACT654 without any issues. Could you please try [Joyride](https://github.com/T-Pau/Joyride)?

What value did you use for RP4? Could you please check its orientation?

gordonfpanam, 2025-05-05:
I ended up borrowing RP5 (4.7k) as I ordered too few of RP5 and RP4 for two builds. I wasn't planning on using the third joystick port immediately, and the schematics for the user port, SID and third joyport suggested that RPs 4 and 5 could be any range from 3.3k to 10k as they were being used for pullups. I figured I could omit U27 until I decided to test the third joyport, so I borrowed its RP.

I've ordered replacements for these and everything else I came up short on, but I can borrow one 8.2k from the second build to test in the meantime. I'll make sure all RPs match the bill of materials once the replacements arrive.

SukkoPera, 2025-05-05:
Yes, that makes sense and should work, as long as the orientation of the part is correct of course.

Please try Joyride.

gordonfpanam, 2025-05-05:
I'm only seeing Joyride for the C64 and C128 Native. Is there a plus/4 version out there?

SukkoPera, 2025-05-05:
Oh, you're right! That was [some wishful thinking](https://github.com/T-Pau/Joyride/issues/4).

I will provide my own test binary ASAP.

SukkoPera, 2025-05-05:
Please try the following:

[snesjtst.zip](https://github.com/user-attachments/files/20049489/snesjtst.zip)

gordonfpanam, 2025-05-06:
This tester works perfect on a stock plus/4. All of the buttons display a unique code, and button combinations come up as intended.

On both of my L16 v4 builds, I’m getting similar results, with specific buttons triggering multiple inputs, and transiting between inputs. It only happens with specific button inputs, with the rest of the buttons working as intended.

I have video of the test and I’ll upload it when I can.

I’m going to put a 6529 back in one of the builds to make sure it isn’t something else up with the user port, but I ran out of time today.

It turns out I was using the intended value for RP4 at 8.1k when using a x654 part, while leaving RP5 and U27 unpopulated.

gordonfpanam, 2025-05-06:
I just swapped in a 6529 to one of the builds, and the TexElec adapter is behaving better, more like the original plus/4 did.

Now I have to find out the difference between the two.

SukkoPera, 2025-05-07:
What do you mean with "behaving better"? Is it working 100% correctly or not?

You should set the scope trigger on latch rising and then monitor clock and data, it's normal for the signals being a bit jittery. But tbh a logic analyzer is a better tool for that, most even have built-in decoders for the controller protocol.

In any case, there should be no difference in behavior between a 6529 and the '654, the circuit should make them behave equally and full compatibility is expected in both cases (and also tested on my side).

NessieSoup is also electrically equivalent to the TexElec adapter, full compatibily is expected in this case just as well. Keep in mind that there are no components on these boards, all they do is connect some userport pins straight to the controller connector pins.

SukkoPera, 2025-05-07:
Can you post a pic of your exact 654 chip?

gordonfpanam, 2025-05-07:
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

I’ve tried two different kinds. The ACT parts are from kits I bought from dmantione at sellmyretro. The LS parts are from a reseller in Ontario. Both behave the same.

I’ll try to post a short video showing what I’m running into.

gordonfpanam, 2025-05-07:
Here we go.

https://youtu.be/9hYZRXYKGTs

SukkoPera, 2025-05-07:
Could you please try reflowing the solder joints of U28 and those of the 654 chip?

gordonfpanam, 2025-05-07:
I'll check on U28 later today. I can reflow the joints, and I have a spare GAL16 from a TED PLA replacement kit. I don't remember what speed it was.

This sounds familiar, needing to use slower GALs on the C64 GAL PLA for certain edge cases.

gordonfpanam, 2025-05-08:
My replacement spares came in, including 4.7k RPs for RP5 and U27, so I was able to reinstall those.

Nothing directly to do with the parallel port, but I tried a 4.7k RP in RP4. The oscillating effect was more pronounced, but I could clearly see X was alternating with A on the tester this time, and the other buttons looked better still.

On a lark I soldered two 4.7k RPs to become a 2.3k RP, and put it in RP4. This seemed to fix all of the buttons.

I was able to use the 7ns GAL in U28 and still have all SNES buttons working.

I don’t yet know any other side effects of using a 2.2k RP in RP4, but I’ve used 1k pull-up resistors in other circuits with open collectors or open drains before, and didn’t see any ill effects.

Maybe the TexElec adapter is just more sensitive to this. What other user port devices are in common use on the plus/4 that this could hurt?

SukkoPera, 2025-05-08:
Well, this is weird, there is no problem with a 2.2k pullup, I just wonder why it was not necessary on my side. The 8.2k value was calculated by Daniel Mantione for [his MOS 6529 replacement](https://www.sellmyretro.com/offer/details/43923) and we just sticked with it.

Glad you fixed the issue, let's leave this open, I guess I'll do more testing at some point...

PS: The TexElec adapter cannot be more sensitive than NessieSoup, as both of them do not contain any components, as mentioned. They just route a few userport lines to the SNES controller, you can remove the adapter altogether if you replace the SNES connector on your controller with a userport connector.

gordonfpanam, 2025-05-08:
Would you like a TexElec SNES adapter sent your way for testing?

SukkoPera, 2025-05-08:
Thanks for the offer but it's not necessary, I have just checked the schematics and they are exactly the same as NessieSoup, as I suspected.

gordonfpanam, 2025-05-18:
I couldn't find any reasonably priced 3.3k packs - right now DigiKey appears to be out of stock and I'd have to order hundreds of them. So I put together a pack of 3.3k resistors to use in RP4, and it's still very stable. This RP value works with both your SNES tester and with the original Plus/4 PETSCII Robots. The 12-bit joypad routine works, as does the 16-bit one from the patched PETSCII Robots.

So a 3.3k value for RP4 seems stable and safe enough at least for the TexElec SNES adapter. 4.7k is still a bit unstable depending on how the software reads the SNES pad. Hopefully that's a good compromise between the TexElec adapter and any other devices that would use the user port's parallel I/O.

SukkoPera, 2025-05-19:
That's some good informations, thanks. Project collaborator @kinmami is looking into this in order to shed some light, as time permits.

Anyway, 2.2k or 3.3k won't change much, I don't expect any incompatibilities. This is all about the time it takes for signals to get from the low level to the high level (it has nothing to do with the current, as some people think), since the userport has open-collector outputs. While it makes sense that some boards expect this to happen "quickly" (meaning lower pull-up resistor values), I can hardly imagine anything requiring this to be slow.

SukkoPera, 2025-05-25:
Tu further prove what @kinmami said, I did some testing applying capacitors to the clock and data lines of the controller, trying to replicate the not fully known design of the TexElec adapter. With 820 pF I can pretty much replicate the issue:

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
This is what happens with the 6529, everything looks normal: purple is clock generated by the computer, light blue is data being shifted out from the controller (on the clock rising edge).

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
This is what happens with a 74x654 with 4.7k pull-ups (what I had on hand): it looks like the controller is unable to push the line down.

I do not understand this. What I expected was that the data signal would be delayed and would not be able to get high again in time before the next bit is sampled.

Bottom line: problem is confirmed but not fully understood. If you remove the capacitors from the adapter, it should work well anyway.

gordonfpanam, 2025-05-25:
I wonder if we can invite TexElec to this conversation. There had to be some reason for him adding those caps, perhaps for the other systems this adapter was meant for.

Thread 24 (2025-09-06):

JiffyDOS Instability depending on CPU

gordonfpanam, 2025-09-06:
On one of three boards I built, JiffyDOS could not reliably read from an SD2IEC device aside from very short BASIC programs.

After trying to use Diag264’s extended port tests and proving P0 through P7 on the CPU, it appears the voltage levels of a high signal on the input pins P7, P6 and P4 seemed lower on the third build compared to the other two. The original got up to 3.22VDC on a high signal but the third only got to 3.11VDC.

After checking and correcting pull-up resistor lines on RP1, it was better but still not stable. By comparison, the stock firmware loader seemed fine, as was the fast loader used by Psytronix games.

Since the stock TED machines treat CPU pins P7 through P4 as inputs at all times, I tried adding pull-up resistors to each. This proved unnecessary for P7 and P6 since RP1 takes care of that, but adding a 10k pull-up to P4 seemed to permanently fix JiffyDOS, at least for my SD2IEC device.

I don’t understand why, since P4 has nothing to do with the IEC port, but it’s an input alongside the others, and P4 didn’t have any kind of pull-up in the schematic. But JiffyDOS is very sensitive to timing issues, and maybe P4 floating caused some issues reading the port register on this third build. Voltages for the P input lines was different, so maybe this third 8501 was more sensitive.

SukkoPera, 2025-09-08:
Let's start with the following:
- P0/1/2/3 are outputs
- P4 is an input that is only used for reading from the Datassette.
- P5 does not exist
- P6/7 are pulled up by RP1

So a couple of things are weird:
- I see no reason why JiffyDOS should use P4, and if it does not, I don't see how that could influence the reading of the other pins unless RP1 is not mounted or not mounted correctly, so please check that.
- I have never measured them, but any pulled-up input pin should measure very close to +5V. The fact that you see ~3V is already suspicious. I will make my own measurements and report back. But again, this could be caused by a bad RP1.
- P4 is not pulled up probably because it only makes sense when it is drive by something else (i.e.: the Datassette) and I would expect that to have a totem-pole output providing sharp edges.

Bottom line: I don't have an explanation for this, but I will take some measurements and then we'll discuss again.

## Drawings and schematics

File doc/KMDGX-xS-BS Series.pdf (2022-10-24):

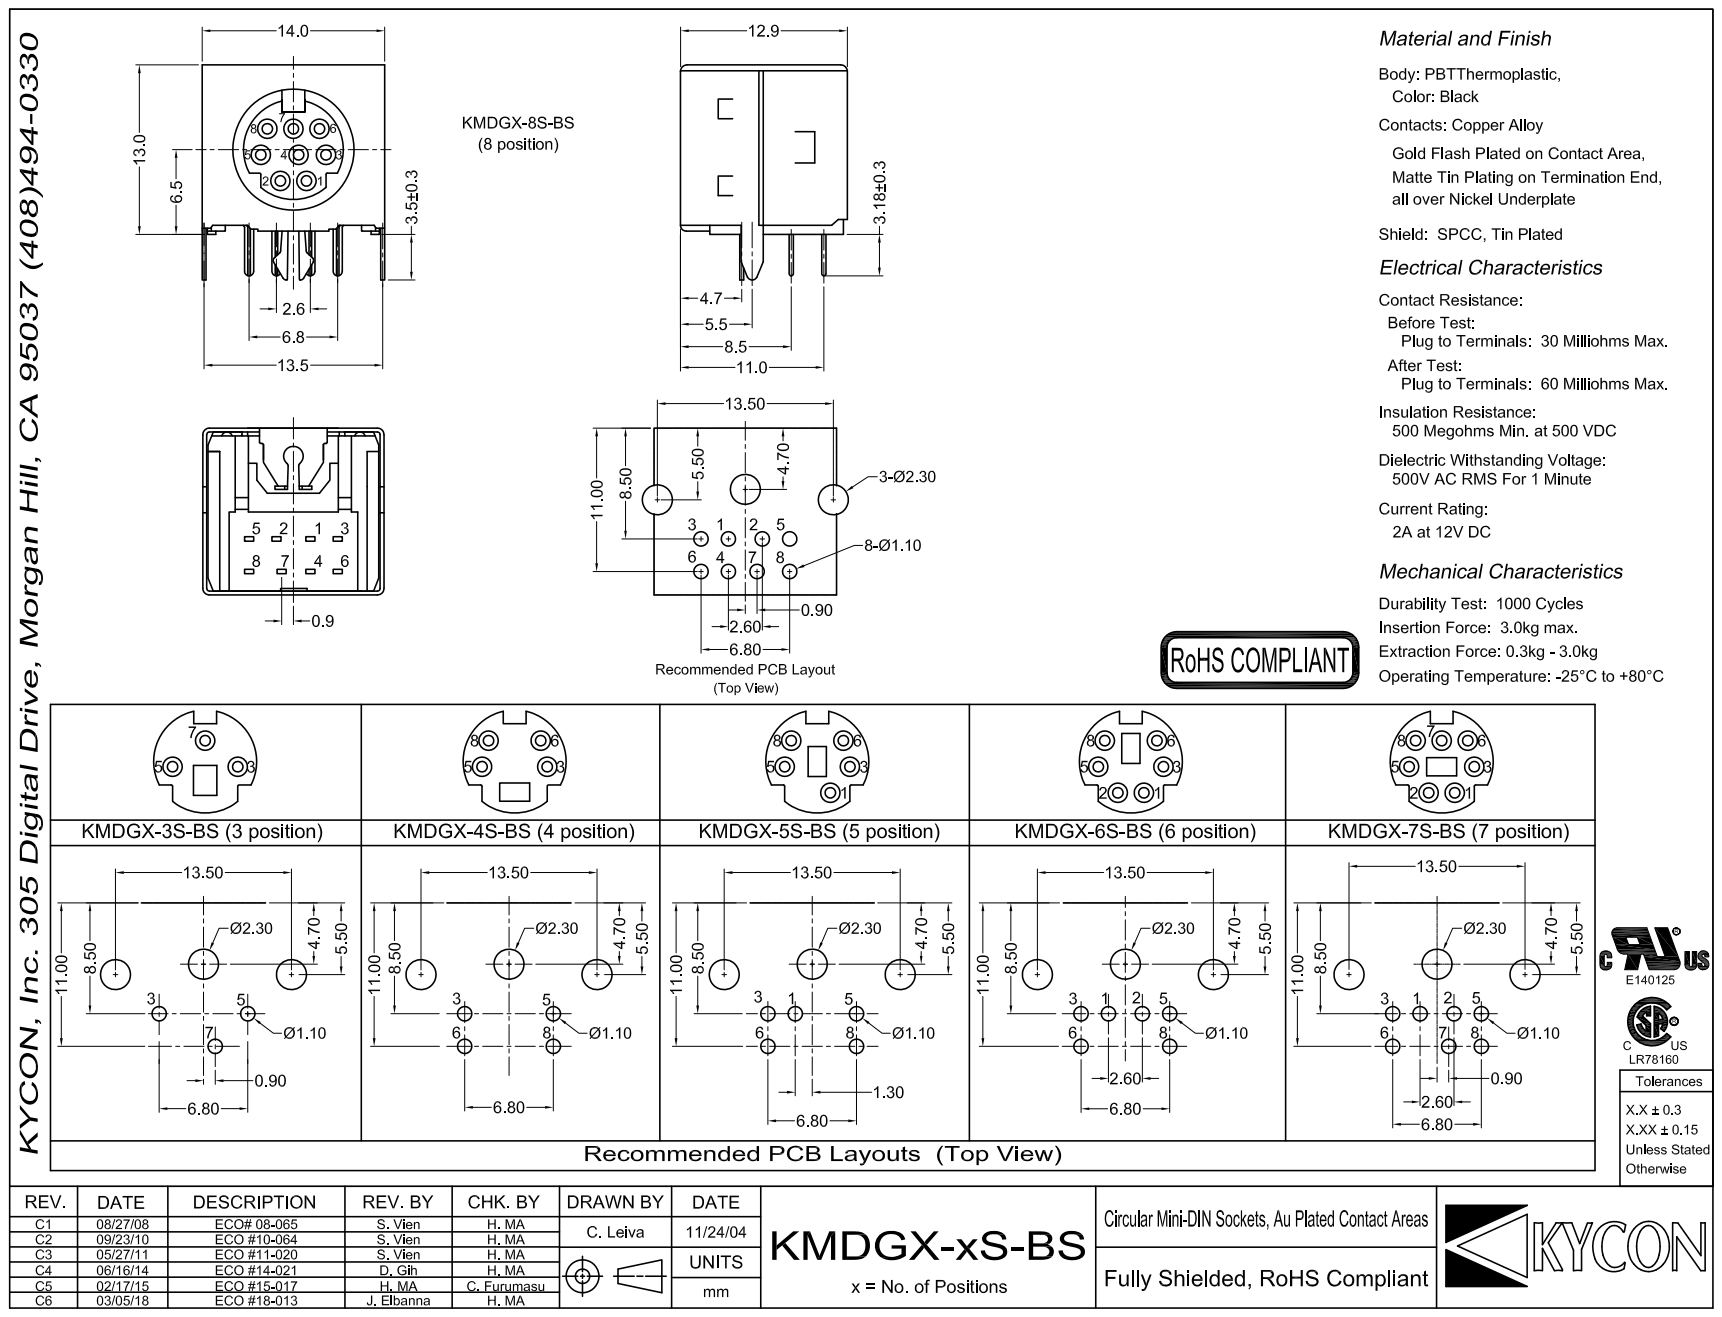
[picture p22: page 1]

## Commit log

2019-11-27 Add RAM and Expansion Port
    [CSeventeen.sch, cpu.sch, exp_port.sch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]
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2019-11-27 Use better library for 74x257's and add power
    [ram.sch]
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2019-11-27 Add reset circuit
    [cpu.sch, ted.sch]
2019-11-28 Add Datassette and power
    [CSeventeen.sch, cpu.sch, datasette.sch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]
2019-11-28 Connect Datassette signals to I/O pins
    [cpu.sch, datasette.sch]
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2019-11-28 Fix label
    [datasette.sch]
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2019-12-02 Add AV output and... we're done!
    [CSeventeen.sch, avout.sch, cpu.sch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]
2020-01-19 Fix schematics here and there
    [CSeventeen.sch, avout.sch, cpu.sch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]
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2020-01-20 Map RP3/4 and add (J)D1/2
    [kbd+joy.sch, ram.sch]
2020-10-04 Fix some errors pointed out by bwack in #1
    [avout.sch, pla.sch]
2020-12-20 Fix for KiCad 5.1.7
    [cpu.sch]
2021-07-13 Start working on PCB
    [CSeventeen.kicad_pcb, avout.sch, cpu.sch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]
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2021-07-13 Fix board dimensions
    [CSeventeen.kicad_pcb]
2021-07-13 Make notches in board outline
    [CSeventeen.kicad_pcb]
2021-07-13 Add EMI filters and ferrites
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2021-07-13 Use 3d models from github.com/StormTrooper/Commodore-Plus4
    [CSeventeen.kicad_pcb, cpu.sch, datasette.sch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]
2021-07-13 CSeventeen -> LittleSixteen (PCB)
    [LittleSixteen.kicad_pcb, avout.sch, datasette.sch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]
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2021-07-14 Complete routing of expansion connector
    [avout.sch, exp_port.sch]
2021-07-14 A whole looooooot of work
    [avout.sch, cpu.sch, datasette.sch]
2021-07-15 Laid out data bus and muuuuch more stuff
    [kbd+joy.sch, misc.sch, ted.sch]
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2021-07-16 One last connection missing!
    [DC Power Jack 5.5mm x 2.1mm.STEP, misc.sch]
2021-07-16 Add holes and exposed copper areas
    [LittleSixteen.sch]
2021-07-19 Turn ferrites the right way
    [kbd+joy.sch]
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2021-07-20 Fix all courtyard issues and work a bit on ground plane
2021-07-20 Work a bit on silkscreen and add logo
    [LittleSixteen.sch]
2021-07-20 Add extra decoupling caps There are actually (unnamed) footprints for these on an actual board, I guess they were skipped for cost saving reasons, sigh...
    [cpu.sch, misc.sch, pla.sch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]
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2021-10-27 Fix orientation of some ferrites
    [avout.sch, datasette.sch, exp_port.sch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]
2021-10-28 Fix tracks to the right of modulator and add 3D models for EMI filters
    [DSN6.FCStd, DSN6.step]
2021-10-30 Add protection diodes and improve clarity
    [datasette.sch]
2021-10-30 Add p4 protection diodes
    [datasette.sch, misc.sch, pla.sch]
2021-10-31 Add CC logo and board URL and update README
    [LittleSixteen.sch]
2021-10-31 Move POR to misc, review some notes
    [LittleSixteen.sch, avout.sch, cpu.sch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]
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2022-10-24 Switch to TSR 2-2450 regulator
    [misc.sch, tsr2_3d_drawing.stp]
2022-10-24 Split kbd+joy into separate sheets
    [LittleSixteen.sch, avout.sch, cpu.sch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]
2022-10-24 Add buffers on joystick ports - WIP
    [joysticks.sch, keyboard.sch, misc.sch]
2022-10-24 Fit alt socket for 6510 Still some fine work TBD
    [avout.sch, cpu.sch, misc.sch]
2022-10-24 Add support for PLA16V8
    [datasette.sch, pla.sch]
2022-10-24 Add note on 6510 CPU
    [cpu.sch]
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2022-10-24 Add 16/64k RAM switch
    [ram.sch]
2022-10-24 Switch to Kycon MiniDIN connectors
    [KMDGX-7S-BS_rC6.step, KMDGX-8S-BS_rC6.step, datasette.sch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]
2022-10-24 Add a way to disable internal RAM from expansion connector
    [exp_port.sch, joysticks.sch, misc.sch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]
2022-10-24 Fix +9V fill
2022-10-24 Add modulator replacement
    [avout.sch]
2022-10-24 Add ability to use a single 64k (EEP)ROM
    [cpu.sch, pla.sch, rom.sch]
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2022-10-24 Add some protection diodes we'd overlooked
    [datasette.sch]
2022-10-24 Position power c'tors, button and reset more accurately Footprints for power and reset buttons need to be checked again
2022-10-24 Make holes for cart connector metal cover
    [LittleSixteen.sch]
2022-10-24 Add diode+resistor to control Datassette motor when using 6510
    [cpu.sch, datasette.sch]
2022-10-24 Fix joystick buffers ^___^
    [joysticks.sch]
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2022-10-24 Rename extra caps and switch to full THT power circuit Well, there's one SMD component, but it's optional :)
    [exp_port.sch, joysticks.sch, keyboard.sch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]
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2022-10-24 Add better ESD protection for Datassette Connector and some notes
    [datasette.sch, pla.sch]
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2022-10-24 Use footprints for DIN connector that we can actually find on the market
    [avout.sch]
2022-10-24 Fix power switch
    [datasette.sch, misc.sch]
2022-10-24 Do not leave input pins of spare gate floating
    [misc.sch]
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2022-10-24 Add current-limiting resistors on joystick ports and start working on silkscreen
    [joysticks.sch]
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2022-10-24 /RAMEN should go to the RAMs' /OE, not to the MUXs'...
    [misc.sch, ram.sch]
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2022-10-24 Add current-limiting resistor on A/V connector Note that there's no ferrite on the +5V pin...
    [avout.sch]
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2022-10-24 Switch joystick ports to DB9 connectors Not sure the power switch still fits. Fixing screws might touch protection diodes, too.
    [joysticks.sch, misc.sch]
2022-10-24 Various minor fixes
    [avout.sch, datasette.sch, joysticks.sch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]
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2022-10-24 Use C64 Datassette Connector This forced us to remove the internal Tapuino/SD2IEC connector, sigh
    [datasette.sch, misc.sch]
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2022-10-24 Enlarge drill holes to 0.9mm in order to make it possible to use ZIF sockets
    [cpu.sch, datasette.sch, joysticks.sch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]
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2022-10-24 Wire R96 in a way that makes sense
    [misc.sch]
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2022-10-24 Fix silkscreen for D12
    [datasette.sch]
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2022-10-24 Add working alternative for 6529 - Thanks @kinmami!
    [keyboard.sch]
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2023-02-25 Realign board on grid Edges are no longer lined on 0.20mm though, sigh
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2023-07-11 Add SID power circuit, to be placed - MISSION IMPOSSIBLE!
    [datasette.sch, misc.sch]
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2023-07-17 Replace joystick buffers with '245s This was done for economy of scale, as we already have other '245s onboard
    [joysticks.sch, misc.sch]
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2023-07-20 Some work on silkscreen, more to do but let's call this RC1
    [sid.sch]
2023-07-20 Remove FB13 For the rationale on this mod, see https://plus4world.powweb.com/forum/46948
    [avout.sch]
2023-07-20 Make all ferrite/EMI filter pins on the same axis
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2023-07-22 Replace L1 with ferrite
    [avout.sch, misc.sch, ram.sch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]
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2023-08-11 Rationalize BOM There should be no significant changes on both schematics on PCB, just some values and something on the silkscreen
    [avout.sch, cpu.sch, datasette.sch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]
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2023-11-17 Fix protruding track
2024-02-05 Add keyboard power jumper and remove pin 2 from keyboard connector
    [keyboard.sch]
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2024-02-23 Add footprint for single oscillator
    [ted.sch]
2024-07-21 Replace /BRESET on Expansion Port and User Port with /RESET This was an oversight we probably introduced in V3 which makes it impossible for the Expansion Port and User Port to reset the machine thro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
    [exp_port.sch, userport.sch]
2024-07-21 Add pull-up network for keyboard buffer Not strictly necessary, boards seems to work fine without, but in principle it should be there
    [keyboard.sch]
2024-07-25 Add a note about datassette Sense This led to https://github.com/sweetlilmre/tapuino/pull/52
    [datasette.sch]
2024-08-07 Add P7 option for Tape Sense jumper, in order to replicate Plus/4 J8/J9
    [datasette.sch, userport.sch]
2024-08-11 Add jumper to select which reset signal is brought to IEC connector
    [datasette.sch, misc.sch]
2024-08-18 Fix screw holes for C16 case
    [LittleSixteen.sch, datasette.sch]
2024-11-13 Add RAM size jumper So we no longer need to reflash PLA2 to change it!
    [misc.sch, ram.sch]
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2025-01-04 Fix all points from #15
    [sid.sch]
2025-01-04 Switch to polyfuses on userport and to ferrites for FB38/39/40
    [exp_port.sch, userport.sch]
2025-06-21 Fix some P/Ns
    [avout.sch, datasette.sch, exp_port.sch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]
2025-06-22 Fix joystick switcher
    [datasette.sch, joysticks.sch, ram.sch]
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2025-06-22 Fix footprint for U17
    [joysticks.sch]
2025-06-22 Use resettable fuses everywhere we do current limiting
    [avout.sch, datasette.sch, joysticks.sch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]
2025-06-22 Do not short JP81/82 by default
    [avout.sch]
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2025-06-29 Minor fixes + P/N updates
    [LittleSixteen.sch, avout.sch, cpu.sch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]
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
